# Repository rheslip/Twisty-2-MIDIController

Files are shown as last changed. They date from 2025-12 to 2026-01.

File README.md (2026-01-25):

# Twisty 2 MIDI Controller
2nd Generation of my Twisty MIDI controller using Raspberry Pi Pico or Pico 2.

The Twisty 2 MIDI controller has 16 parameter encoders with switches, 16 RGB LEDs, 2 menu encoders, 128x32 pixel OLED display, USB MIDI, TRS MIDI Out, and optional Bluetooth MIDI with Pico W or Pico 2W.
It provides four pages of MIDI controls and fully customizable MIDI messages, encoder ranges, switch functions and LED colors for each control. Text labels can be attached to each control as a visual aid to what the control does. You can save and recall up to 16 controller setups in the Pico's flash memory. STL files for a 3D printed case are provided as well.

Twisty 2 is a completely open source project - source code, KICad schematics and layout, gerber files and enclosure 3D files are in this archive.

Video Overview: https://youtu.be/-W1Gd_hKzS8

Jan 13/2026 - switched MIDI interfaces so they all use the Control Surface library and cleaned up the MIDI interface names - BLE MIDI note on/off works now. Fixed a bug in the init code. 

Jan 25/2026 - added code for a Moog SubHarmonicon like sequencer using the Twisty 2 hardware:

https://www.youtube.com/watch?v=RM_LAcxyHQQ

https://github.com/rheslip/Twisty-2-MIDIController/tree/main/source/Twisty2_Rhythmicon

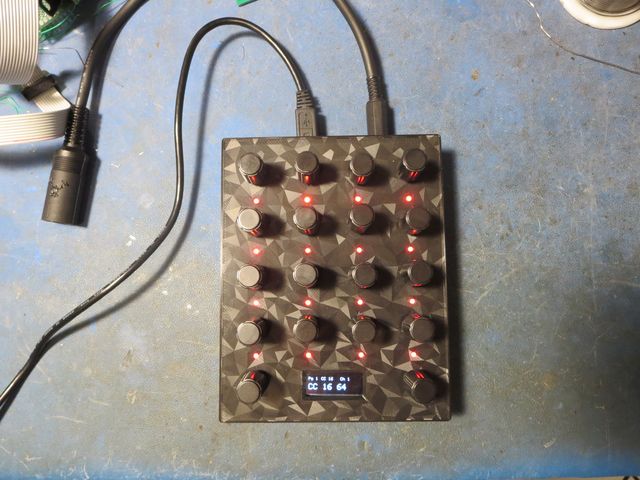
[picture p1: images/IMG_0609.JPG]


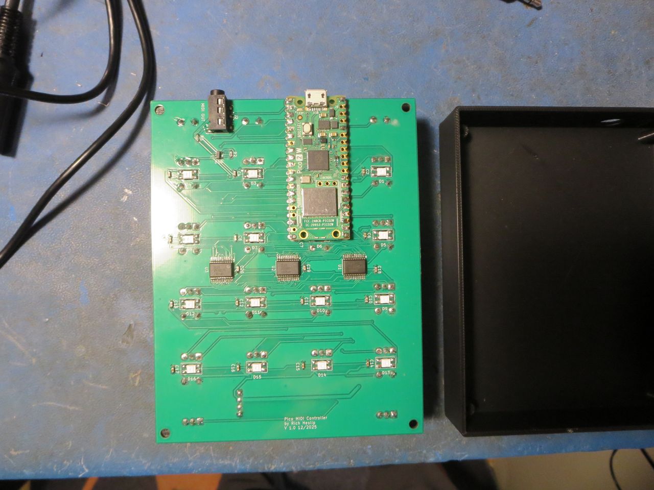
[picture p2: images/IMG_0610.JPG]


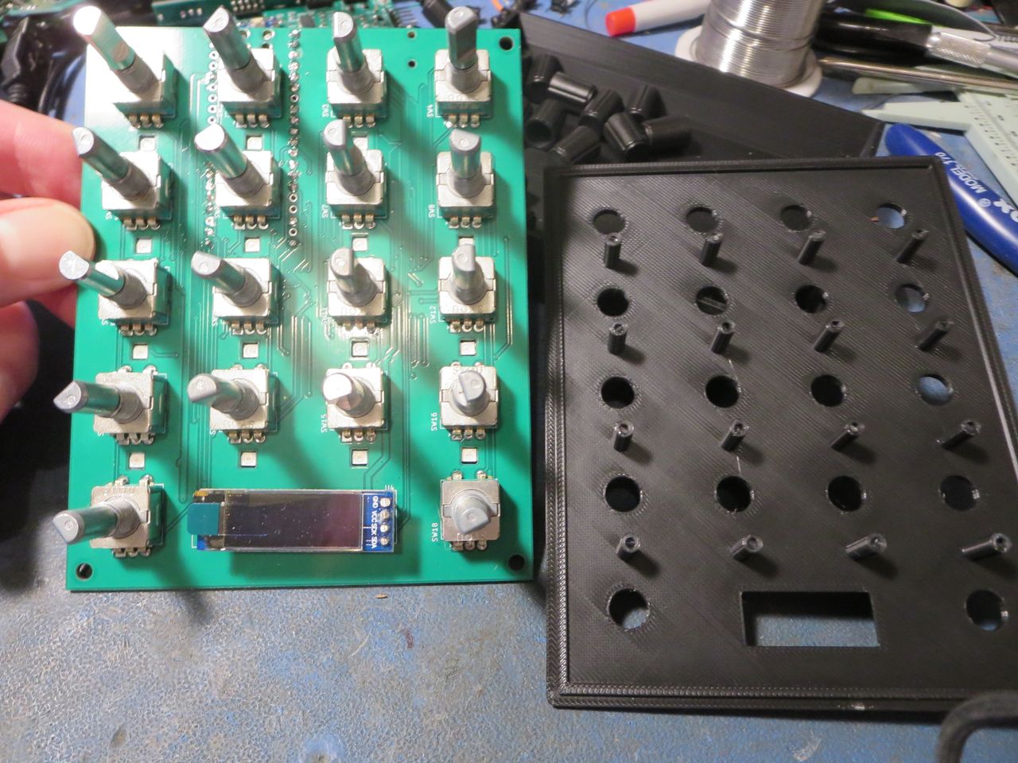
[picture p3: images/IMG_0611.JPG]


**Build Guide**

Solder the .1u caps, resistors and the diode. Solder the 16 SK6812 RGB leds making sure the orientation is correct and that the LEDs face the top side of the PCB. Solder the TRS MIDI out jack.

Solder the TSSOP 74HC4067s. I apply a very thin layer of flux to the pads and place the chip so its aligned on the pads. Using a fine tipped soldering iron tack one pin down with solder, adjust as needed and when the part is correctly aligned tack another pin down. Make sure the pins are sitting flat on the pads before you solder the rest. Solder each pin with very fine solder and don't worry about shorts between pins. Once all the pins are soldered examine your work with a magnifier and remove any shorts beween pins with fine solder wick.

Clip the support lugs off all the encoders - there was not enough room in the layout to accomodate them. The encoders have good mechanical support from the enclosure top anyway. The encoders mount from the TOP side of the board and are soldered on the bottom side. You **MUST** solder S2, S6, D2 and D6 **BEFORE** mounting the Pico board. Soldering S2, S6 and then the Pico makes soldering the Pico somewhat easier than soldering all the encoders first.

After all the encoders are soldered, mount the OLED display - temporarily mount the enclosure top as a guide to get the spacing from the display to the top correct.

Hardest part of the build is soldering the three TSSOP 74HC4067 analog MUXes. If encoders aren't working, recheck the soldering on these chips - most faults will be here! Rest of the build is straightforward.

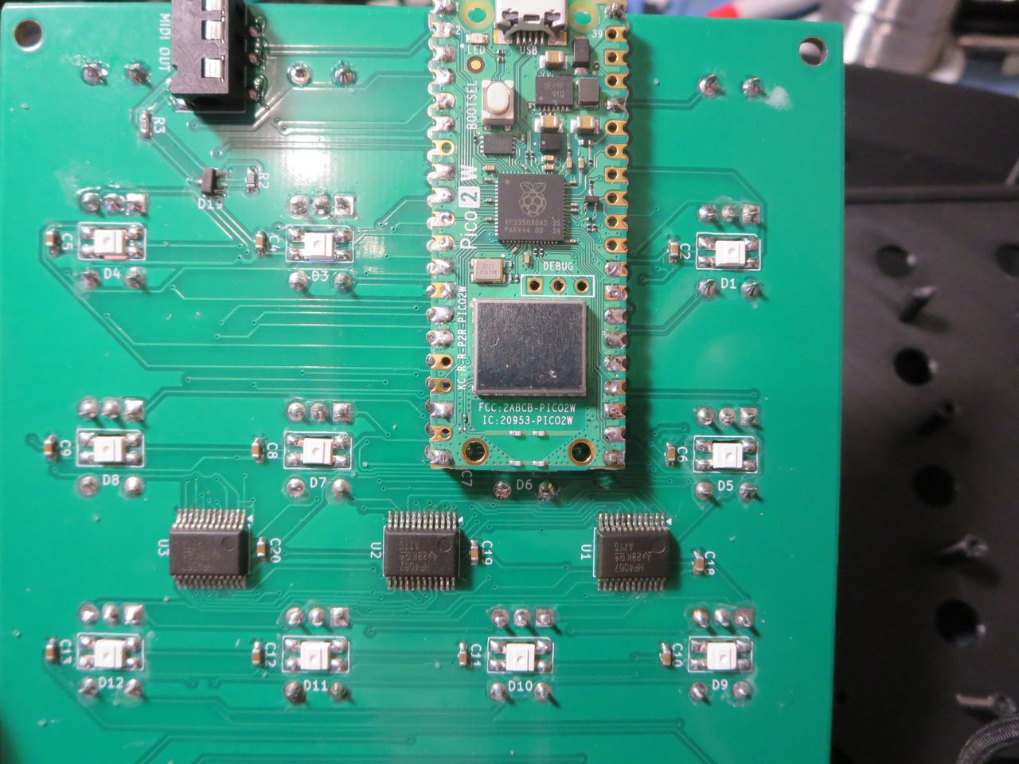
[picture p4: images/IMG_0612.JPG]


Pico can be mounted with header strips. I used header pins in the corners and short wires to connect the Pico to the PCB which makes the Pico board a lot easier to remove if needed.

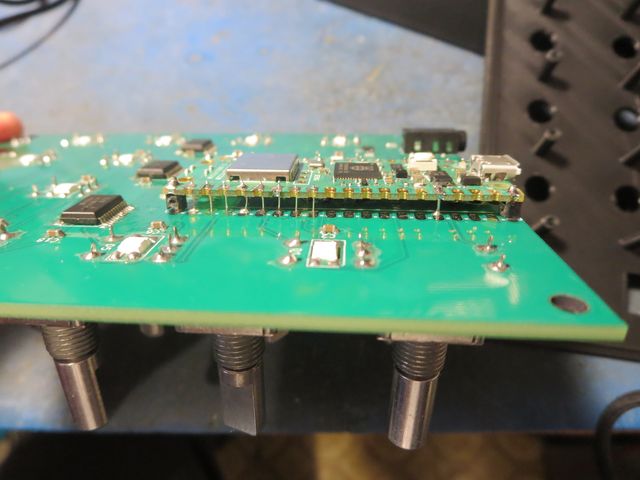
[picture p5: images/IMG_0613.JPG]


Side view of OLED mounting

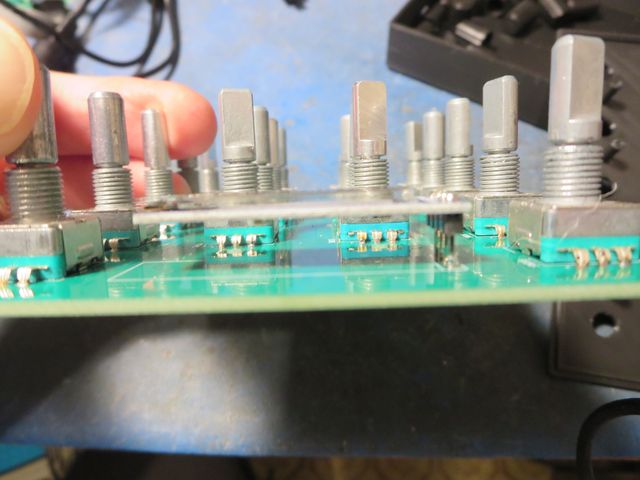
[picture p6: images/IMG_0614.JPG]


**Enclosure**

The prototype enclosure was printed on a Bambu P1S with black PLA+ filament. For the most part the stock filament settings were used. Slowing down the first layer speeds by 50% helps with adhesion and finish if you are using a textured build plate. The light pipe holes in the top had to be drilled a bit to fit 1.75mm transparent PETG which was lightly glued to hold it in place. Use small screws to attach the PCB to the standoffs in the enclosure bottom. Slide the enclosure top over the encoder shafts and hold it in place with encoder nuts.

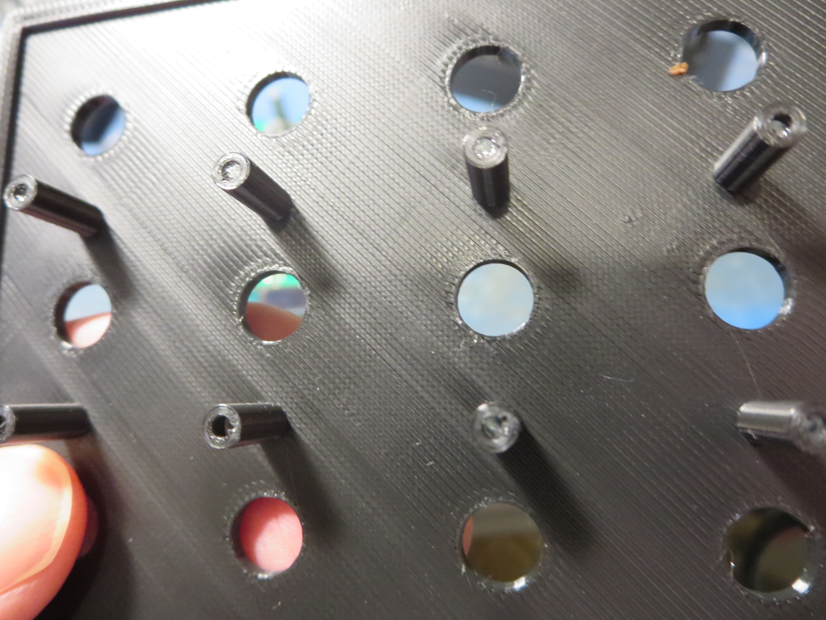
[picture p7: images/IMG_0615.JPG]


**User Guide**

The top 16 controls (control=encoder+switch) are used to send MIDI CC messages, program change messages or or note on/off messages depending on how the controls are configured. The two extra controls at the bottom are used in conjunction with the OLED display to configure controls, save configurations and recall configurations.

The RGB LEDs associated with each control normally show the state of whatever was last used - encoder as a color and switch states as off or bright white. Encoder LED brightness changes as the control is moved to give a relative idea of the encoder setting. Double click the bottom left control to toggle between showing encoder states and switch states.

Rotate bottom left encoder to move between the 4 pages of controls. Default colors for each page are Red (page 1), Orange (page 2), Green (page ) and Aqua (page 4).

The top line of the OLED display shows the current page, the last used control, its message type and MIDI channel. The larger text below that shows a label if one has been configured and the last value that was sent for that control.

**The Configuration Menu**

Clicking the bottom left control will bring up a configuration menu to edit the last control that was used. The LED for that control will flash to indicate it is selected for editing. To select a different control when in edit mode either press a control switch to choose it or use bottom left encoder to scroll to a different control on the current page.

When in edit mode use the bottom right encoder the scroll through the edit menu items. Click the bottom right control switch to select an item - a "*" character will appear beside the item to indicate it is being edited. Use the bottom right encoder to change the value for the item and click the bottom right encoder switch to select a value.

Click the bottom left encoder again to exit the configuration edit menu.

**Configuration Menu Items:**

**Enc MIDI Ch.** - selects the MIDI channel that the selected encoder will send CC messages on

**Enc CC No.**  - selects the CC number for this encoder. The default CC assignments are 16-31 for page 1, 32-47 for page 2, 48-63 for page 3 and 64-79 for page 4

**Enc Label** - default is "CC". There are approximately 100 common audio terms (e.g. "Level", "Filter", "Track"...) that can be selected as an aid for remembering the function of the control. The label will be displayed instead of the CC number whenever this encoder is used.

**Enc Color** - selects the LED color for this encoder - Red, Orange, Green, Aqua, Blue or Violet. This is useful for grouping control functions by color.

**Enc Min** - minimum CC value that will be sent when the encoder is rotated - defaults to 0

**Enc Max** - maximum CC value that will be sent when the encoder is rotated - defaults to 127. 
**Note** If the minimum setting is higher than the maximum the encoder will reverse ie rotating clockwise sends a lower CC value.

**Switch MIDI Ch.** - selects the MIDI channel that the selected switch will send CC messages on

**Switch Mode** - selects either momentary mode (press for max value, release for min value) or toggle mode (select min or max value on alternate presses)

**Switch Type** - selects switch function:

     **CC** = send CC messages 
 
     **PC** = send program change messages
 
     **Note** = send Note on/off messages
 
     **SetEnc** = when the switch is activated, set the associated encoder on this control to Maxvalue. This provides a quick way to set an encoder to a specific value e.g. set a filter to flat response.
 
**Switch CC No.** - selects the CC number for this switch. This selection only applies when the switch type is send CC messages. The default switch CC assignments are the same as the associated encoder but on MIDI channel 2. 

**Switch Label** - same as encoder label - a memory aid for what the switch does

**Switch Min** - CC, PC or note value sent when the switch changes to its inactive state. defaults to 0

**Switch Max** - CC, PC or note value sent when the switch changes to its active state. defaults to 127. When switch type is SetEnc, sets associated encoder to this value.

**The Save/Load Menu**

Clicking the bottom right encoder enters the save/load menu. Twisty 2 supports saving and loading up to 16 different configurations in the Pico's flash memory.

**Note** You must select an FS size in the Arduino Pico Tools menu - 128K or larger is suggested. The application will automatically format a new FS if it has not been used before. Internally the application uses the LittleFS filesystem and stores configurations as JSON files.

**Save/Load Menu Items:**

**Slot** - selects the slot number 1-16 to save the current configuration to.

**Action** - select Load to load an already saved configuration from the selected slot. Save will save the current configuration to the selected slot. Format will reformat the LittleFS partition - this will ERASE ALL previously saved configurations.

**Confirm** - select Yes to confirm the selected action. The app will **NOT** warn you if you are about to overwrite an existing configuration. If Yes is selected the requested action will be performed, a success/fail message will appear and the Save/load Menu will exit.

**Note** You will get an error message if you attempt to load a configuration slot that hasn't previously been saved to.

To exit the Save/Load menu without changing anything click the bottom left control switch.

**Building the Firmware**

The app was written in Arduino 2.3.7 with the Pico Arduino board support package installed. Select the board type as Pico, Pico 2, Pico 2 or Pico 2W depending on the board you used. The prototype was tested with both a Pico W and a Pico 2 W. In the tools menu select the FS size you want (128k or more is recommended), IP/Bluetooth stack as IPV4 + Bluetooth if you want BLE MIDI, and select the USB stack as Adafruit TinyUSB. This app should not need overclocking since the CPU demands are light.

If you want BLE MIDI, use a Pico W or Pico 2W and uncomment the #define BLUETOOTH directive near the top of the main source file.

Note: I used the Control Surface library because it was the only one I could find that supports BLE MIDI for Arduino Pico. It will give you a warning about supported platforms when you compile but the library does work on the RP2040 and RP2350.

**Library Dependencies**

Adafruit Graphics

Adafruit SSD1306 driver

Adafruit TinyUSB

Adafruit NeoPixel

Arduino MIDI

Arduino JSON  https://arduinojson.org/

Control Surface  https://github.com/tttapa/Control-Surface

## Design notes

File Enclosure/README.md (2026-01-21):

Enclosure files for the Twisty 2 MIDI Controller

There are two versions of the base - one has cutouts for the Pico USB connector and the TRS MIDI jack, and another which adds cutouts for a slide switch and USB-C for a battery charger module.

I used a 1S TP4056 5V 28x17mm module from Aliexpress. The case has a little box to hold the module - put some 2mm thick double sided tape in the bottom of the box and press the module into place. Its tight so the module may need a little sanding to fit.
Make sure you change the charging rate to a safe level for your battery! On the modules I bought R3 adjusts the charge rate - see the TP4056 datasheet.

https://www.aliexpress.com/item/1005007730039023.html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

The stepup regulator is a 0.9v to 5V input, 5V output module. Solder the GND pin to Pico pin 38 GND and the 5V output pin to Pico pin 39 VSys. I added a 10k:10k divider from battery input Vin to GND with the center to pin 34 ADC3 which allows the battery voltage to be monitored.

https://www.aliexpress.com/item/1005003375824265.html?spm=a2g0o.order_list.order_list_main.369.4d9a1802hPwpIL

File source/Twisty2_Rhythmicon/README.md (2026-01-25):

# PicoRhythmicon - a Subharmonicon-like sequencer using the Twisty 2 MIDI Controller hardware

The Twisty 2 was designed to be a MIDI controller but also as a platform for creating other MIDI devices. This one is a sequencer similar to the Moog Subharmonicon. The Subharmonicon sequencer is based on a very old polyrhythmic instrument called the Rhythmicon.

Demo and tutorial video: 

I suggest you also watch a tutorial video on the Moog Subharmonicon to get a better understanding of how this sequencer works.

**User Guide**

The top 16 encoders are set up as three rows of (four step) sequencers and a bottom row of clock dividers. Notes are set by rotating the encoders. The top three rows of the display show the MIDI notes that will be sent for each step of the three sequencers. The display shows the clock divider values on the botton row.

The 4 clock divider LED colors are (L-R) Red, Green, Blue and Purple. Rotate the encoders counterclockwise to increase the divider i.e. slow down the clock. To connect a clock divider to a sequencer, press the encoder button on the sequencer's row that corresponds to the clock divider's column. The step encoder's LED will change to the same color as the clock divider to indicate that sequencer is connected to that divider.

The internal master clock is 24 pulses per quarter note/6 = sixteenth notes when the clock divider is set to 1. Changing the clock divider to 2 results in eighth notes, 3 is dotted eighths, 4 is quarter note etc. The maximum clock divider is 128 which is 8 bars. If a 24 PPQN MIDI clock is sent to the PicoRhythmicon via it's USB or BLE MIDI interface it will automatically sync to it. It also responds to MIDI transport messages.

**The Setup Menu**

Clicking the bottom right encoder will bring up a setup menu. When in edit mode use the bottom right encoder the scroll through the edit menu items. Click the bottom right control switch to select an item - a "*" character will appear beside the item to indicate it is being edited. Use the bottom right encoder to change the value for the item and click the bottom right encoder switch to select a value. Click the bottom left encoder or double click the bottom right encoder to exit the setup menu.

**Setup Menu Items:**

Each of the three sequencers has these setup options:

**Root** - root note for the scale quantizer (default C3 MIDI note 60). The note for any given step is the root note plus an offset adjusted by the step's encoder.

**Scale**  - selects the scale for the sequencer from CHROMATIC, MAJOR, MINOR, HARMONIC_MINOR, MAJOR_PENTATONIC, MINOR_PENTATONIC, DORIAN, PHRYGIAN, LYDIAN, or MIXOLYDIAN. The note shown on the display is the quantized value. Because of this you may have to rotate the encoder a few steps to get to the next note in the scale.

**Step mode** - changes the way the sequencer steps from one note to the next: 

Fwd - steps from left to right

Rev - steps from right to left

Pong - reverses direction on the first and last steps

Walk - random walk - the sequencer randomly steps to the right or the left 

Rand - a random step is chosen

**MIDI Out** - MIDI channel that this sequencer will send notes on

**MIDI In** - MIDI channel that this sequencer will respond to incoming transpose notes. Transpose is calculated as an offset from MIDI note 60, which is added to the root note plus an offset adjusted by the step's encoder. i.e. the note sent on any given step is calculated as root + step offset + (transpose note - 60)

**BPM** - sets the internal clock BPM. As noted above, the unit will sync to an external MIDI clock sent via the BLE or USB interfaces.

**Bat Voltage** - shows the battery voltage if the hardware supports it. See the enclosure README file for the hardware mods needed for battery operation.

**Building the Firmware**

The app was written in Arduino 2.3.7 with the Pico Arduino board support package installed. Select the board type as Pico, Pico 2, Pico 2 or Pico 2W depending on the board you used. The prototype was tested with both a Pico W and a Pico 2 W. In the tools menu select IP/Bluetooth stack as IPV4 + Bluetooth if you want BLE MIDI, and select the USB stack as Adafruit TinyUSB. This app should not need overclocking since the CPU demands are light.

If you want BLE MIDI, use a Pico W or Pico 2W and uncomment the #define BLUETOOTH directive near the top of the main source file.

Note: I used the Control Surface library because it was the only one I could find that supports BLE MIDI for Arduino Pico. It will give you a warning about supported platforms when you compile but the library does work on the RP2040. It will also work on the RP2350 but requires some modifications to the conditionals to compile correctly.

**Library Dependencies**

Adafruit Graphics

Adafruit SSD1306 driver

Adafruit TinyUSB

Adafruit NeoPixel

Control Surface  https://github.com/tttapa/Control-Surface

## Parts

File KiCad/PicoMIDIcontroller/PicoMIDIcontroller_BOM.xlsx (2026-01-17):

Reference | Qty | Value | Footprint | Link | Comments | Datasheet
A1 | 1 | RaspberryPi_Pico |  |  | Pico,Pico W, Pico2, Pico 2W | https://datasheets.raspberrypi.com/pico/pico-datasheet.pdf
C2,C3,C4,C5,C6,C7,C8,C9,C10,C11,C12,C13,C14,C15,C16,C17,C18,C19,C20 | 19 | .1u | 0603 |  |  | ~
D1,D2,D3,D4,D5,D6,D7,D8,D9,D10,D11,D12,D13,D14,D15,D16 | 16 | SK6812E-MINI | SK6812_MINI-E_rearmount | https://www.aliexpress.com/item/1005005193716172.html | best price is on Aliexpress | https://cdn-shop.adafruit.com/product-files/2686/SK6812MINI_REV.01-1-2.pdf
D19 | 1 | BAT54S | SOT-23 |  | make sure you use the "S" pinout | https://www.diodes.com/assets/Datasheets/ds11005.pdf
H1,H2,H3,H4 | 4 | MountingHole | 3.2mm_M3 |  |  | ~
J2 | 1 | AudioJack4 | PJ-320D-4A_Horizontal | https://www.aliexpress.com/item/1005010770707376.html?curPageLogUid=zL5tGp3dUZi3 | SMT, 3 leads on one side, one on the other | ~
R2 | 1 | 33 | 0603 |  |  | ~
R3 | 1 | 10 | 0603 |  |  | ~
SW1,SW2,SW3,SW4,SW5,SW6,SW7,SW8,SW9,SW10,SW11,SW12,SW13,SW14,SW15,SW16,SW17,SW18 | 18 | RotaryEncoder_Switch | EC11E-Switch_Vertical | https://www.digikey.ca/en/products/detail/bourns-inc/PEC11R-4220F-S0024/4499660 | PEC11R-4020F-S0024 - no detents, PEC11R-4220F-S0024 24 detents. Very cheap on Aliexpress | https://www.bourns.com/docs/Product-Datasheets/PEC11R.pdf
U1,U2,U3 | 3 | CD74HC4067PWR | 24-TSSOP 7.8mm × 6.4mm | https://www.digikey.ca/en/products/detail/texas-instruments/CD74HC4067PWR/26639687 |  | http://www.ti.com/lit/ds/symlink/cd74hc4067.pdf
U4 | 1 | SSD1603_OLED | 1x04_P2.54mm_Vertical | https://www.aliexpress.com/item/32672229793.html | available on Amazon as well

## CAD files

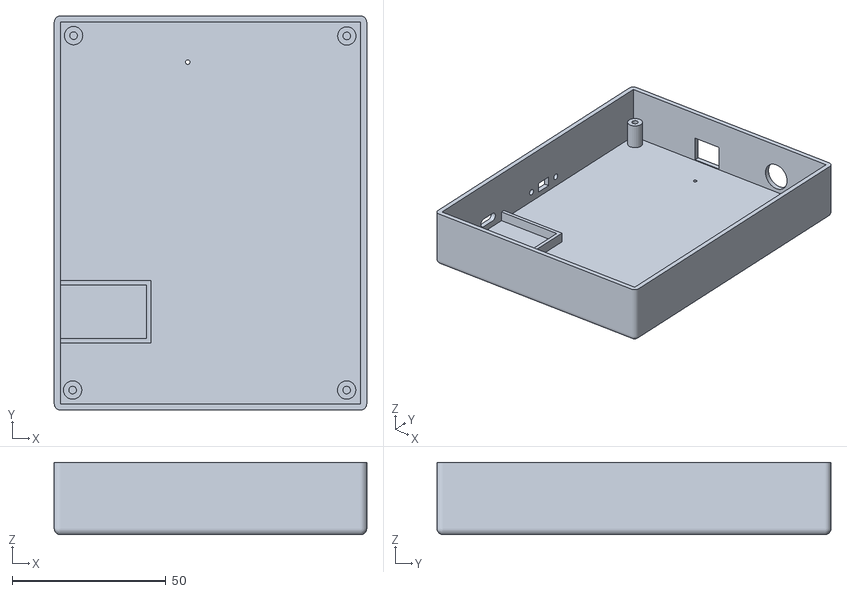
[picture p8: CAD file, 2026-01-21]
Enclosure/Pico Midicontroller Base Battery Powered.stl
101.8 x 128.3 x 23.6

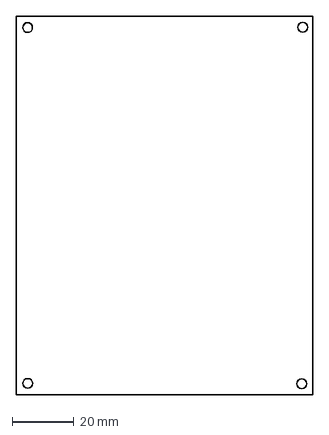
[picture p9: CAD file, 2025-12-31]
KiCad/PicoMIDIcontroller/PCB Outline.dxf
95.8 x 122.3 mm

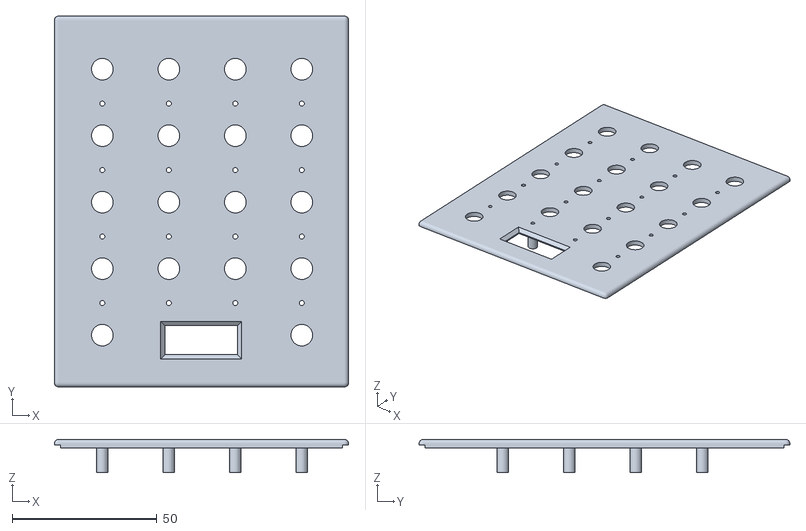
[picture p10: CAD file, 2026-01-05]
Enclosure/Pico MIDIcontroller Top.stl
101.8 x 128.3 x 11.5

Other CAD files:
Enclosure/Pico MIDIController Base.stl

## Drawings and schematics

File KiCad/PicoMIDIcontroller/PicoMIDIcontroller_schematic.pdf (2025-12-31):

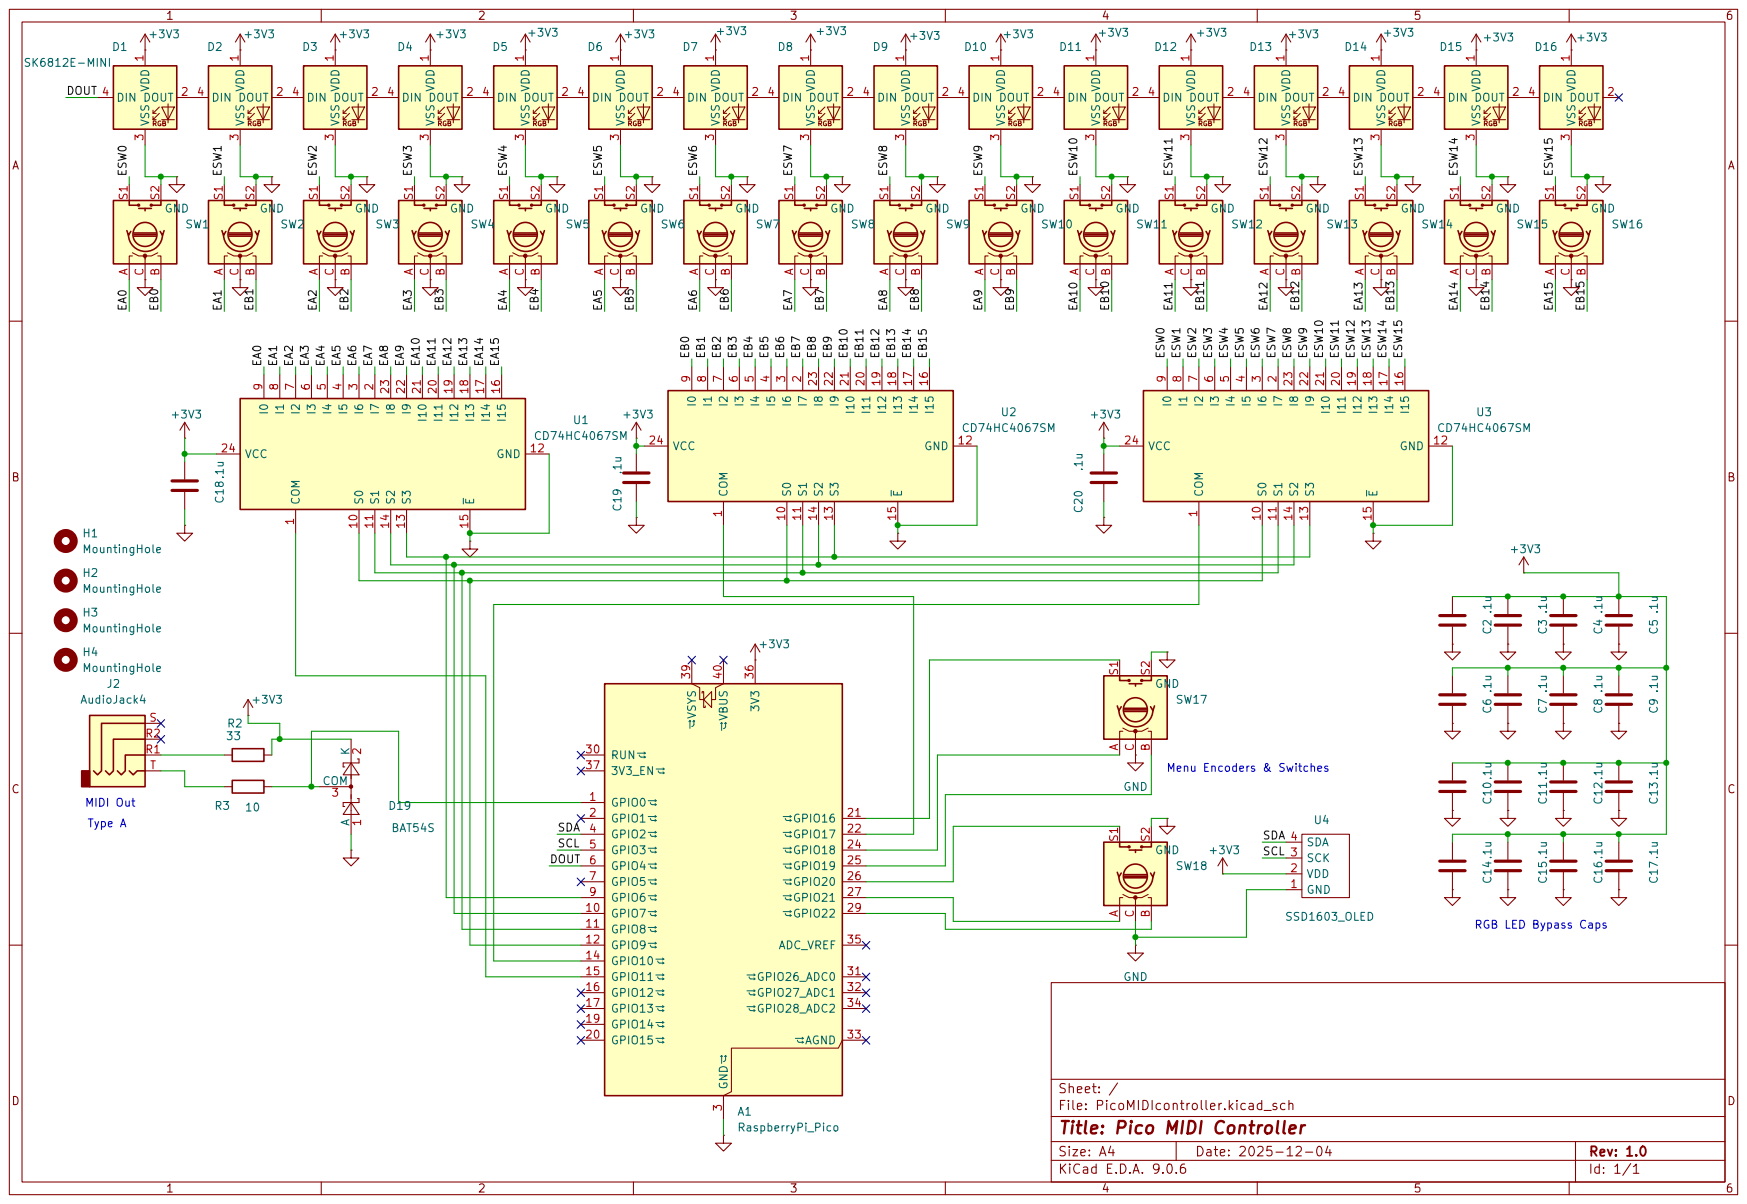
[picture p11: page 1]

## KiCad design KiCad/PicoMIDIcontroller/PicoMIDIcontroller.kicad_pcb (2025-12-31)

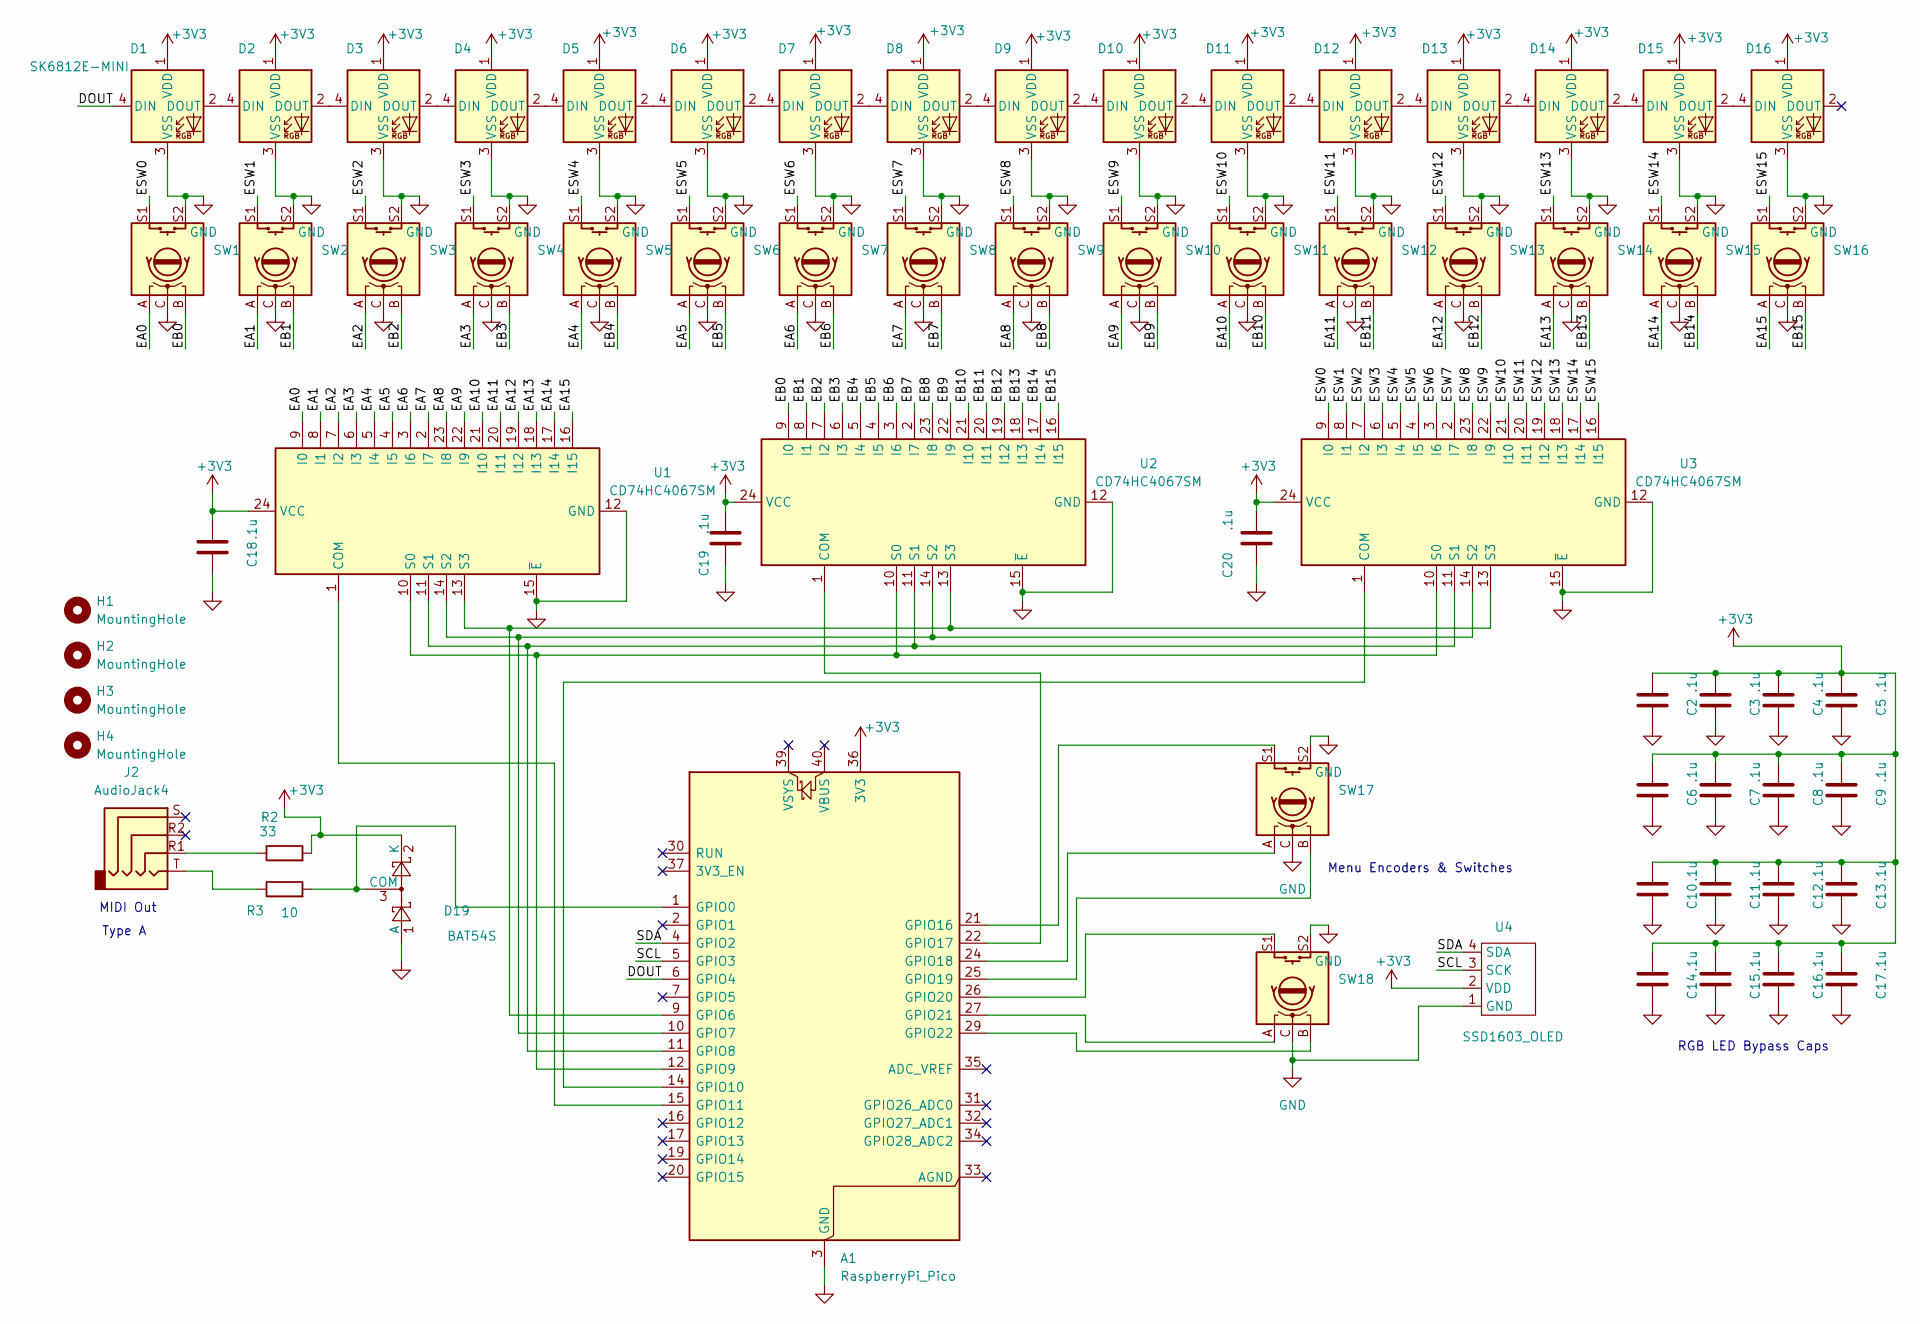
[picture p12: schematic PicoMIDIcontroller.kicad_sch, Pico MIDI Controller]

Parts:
A1: RaspberryPi_Pico; RaspberryPi_Pico_Common_nokeepout
C2, C3, C4, C5, C6, C7, C8, C9, C10, C11, C12, C13, C14, C15, C16, C17, C18, C19, C20: .1u; C_0603_1608Metric_Pad1.08x0.95mm_HandSolder
D1, D2, D3, D4, D5, D6, D7, D8, D9, D10, D11, D12, D13, D14, D15, D16: SK6812E-MINI; LED_OPSCO_SK6812_MINI-E_5.0x5.0mm_P3.1mm_rearmount
D19: BAT54S; SOT-23
H1, H2, H3, H4: MountingHole; MountingHole_3.2mm_M3
J2: AudioJack4; Jack_3.5mm_KoreanHropartsElec_PJ-320D-4A_Horizontal
R2: 33; R_0603_1608Metric_Pad0.98x0.95mm_HandSolder
R3: 10; R_0603_1608Metric_Pad0.98x0.95mm_HandSolder
SW1, SW2, SW3, SW4, SW5, SW6, SW7, SW8, SW9, SW10, SW11, SW12, SW13, SW14, SW15, SW16, SW17, SW18: RotaryEncoder_Switch; RotaryEncoder_Alps_EC11E-Switch_Vertical_H20mm_topsolder
U1, U2, U3: CD74HC4067SM; SSOP-24_5.3x8.2mm_P0.65mm
U4: SSD1603_OLED; PinHeader_1x04_P2.54mm_Vertical

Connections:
+3V3: A1.36 (3V3), C2.2, C3.2, C4.2, C5.2, C6.2, C7.2, C8.2, C9.2, C10.2, C11.2, C12.2, C13.2, C14.2, C15.2, C16.2, C17.2, C18.2, C19.2, C20.2, D1.1 (VDD), D2.1 (VDD), D3.1 (VDD), D4.1 (VDD), D5.1 (VDD), D6.1 (VDD), D7.1 (VDD), D8.1 (VDD), D9.1 (VDD), D10.1 (VDD), D11.1 (VDD), D12.1 (VDD), D13.1 (VDD), D14.1 (VDD), D15.1 (VDD), D16.1 (VDD), D19.2 (K), R2.2, U1.24 (VCC), U2.24 (VCC), U3.24 (VCC), U4.2 (VDD); also elsewhere on the board
/DOUT: A1.6 (GPIO4), D1.4 (DIN); also elsewhere on the board
/EA0: SW1.A, U1.9 (I0)
/EA1: SW2.A, U1.8 (I1)
/EA2: SW3.A, U1.7 (I2)
/EA3: SW4.A, U1.6 (I3)
/EA4: SW5.A, U1.5 (I4)
/EA5: SW6.A, U1.4 (I5)
/EA6: SW7.A, U1.3 (I6)
/EA7: SW8.A, U1.2 (I7)
/EA8: SW9.A, U1.23 (I8)
/EA9: SW10.A, U1.22 (I9)
/EA10: SW11.A, U1.21 (I10)
/EA11: SW12.A, U1.20 (I11)
/EA12: SW13.A, U1.19 (I12)
/EA13: SW14.A, U1.18 (I13)
/EA14: SW15.A, U1.17 (I14)
/EA15: SW16.A, U1.16 (I15)
/EB0: SW1.B, U2.9 (I0)
/EB1: SW2.B, U2.8 (I1)
/EB2: SW3.B, U2.7 (I2)
/EB3: SW4.B, U2.6 (I3)
/EB4: SW5.B, U2.5 (I4)
/EB5: SW6.B, U2.4 (I5)
/EB6: SW7.B, U2.3 (I6)
/EB7: SW8.B, U2.2 (I7)
/EB8: SW9.B, U2.23 (I8)
/EB9: SW10.B, U2.22 (I9)
/EB10: SW11.B, U2.21 (I10)
/EB11: SW12.B, U2.20 (I11)
/EB12: SW13.B, U2.19 (I12)
/EB13: SW14.B, U2.18 (I13)
/EB14: SW15.B, U2.17 (I14)
/EB15: SW16.B, U2.16 (I15)
/ESW0: SW1.S1, U3.9 (I0)
/ESW1: SW2.S1, U3.8 (I1)
/ESW2: SW3.S1, U3.7 (I2)
/ESW3: SW4.S1, U3.6 (I3)
/ESW4: SW5.S1, U3.5 (I4)
/ESW5: SW6.S1, U3.4 (I5)
/ESW6: SW7.S1, U3.3 (I6)
/ESW7: SW8.S1, U3.2 (I7)
/ESW8: SW9.S1, U3.23 (I8)
/ESW9: SW10.S1, U3.22 (I9)
/ESW10: SW11.S1, U3.21 (I10)
/ESW11: SW12.S1, U3.20 (I11)
/ESW12: SW13.S1, U3.19 (I12)
/ESW13: SW14.S1, U3.18 (I13)
/ESW14: SW15.S1, U3.17 (I14)
/ESW15: SW16.S1, U3.16 (I15)
/SCL: A1.5 (GPIO3), U4.3 (SCK); also elsewhere on the board
/SDA: A1.4 (GPIO2), U4.4 (SDA); also elsewhere on the board
GND: A1.3 (GND), A1.8 (GND), A1.13 (GND), A1.18 (GND), A1.23 (GND), A1.28 (GND), A1.38 (GND), C2.1, C3.1, C4.1, C5.1, C6.1, C7.1, C8.1, C9.1, C10.1, C11.1, C12.1, C13.1, C14.1, C15.1, C16.1, C17.1, C18.1, C19.1, C20.1, D1.3 (VSS), D2.3 (VSS), D3.3 (VSS), D4.3 (VSS), D5.3 (VSS), D6.3 (VSS), D7.3 (VSS), D8.3 (VSS), D9.3 (VSS), D10.3 (VSS), D11.3 (VSS), D12.3 (VSS), D13.3 (VSS), D14.3 (VSS), D15.3 (VSS), D16.3 (VSS), D19.1 (A), SW1.C, SW1.S2, SW2.C, SW2.S2, SW3.C, SW3.S2, SW4.C, SW4.S2, SW5.C, SW5.S2, SW6.C, SW6.S2, SW7.C, SW7.S2, SW8.C, SW8.S2, SW9.C, SW9.S2, SW10.C, SW10.S2, SW11.C, SW11.S2, SW12.C, SW12.S2, SW13.C, SW13.S2, SW14.C, SW14.S2, SW15.C, SW15.S2, SW16.C, SW16.S2, SW17.C, SW17.S2, SW18.C, SW18.S2, U1.12 (GND), U1.15 (~E), U2.12 (GND), U2.15 (~E), U3.12 (GND), U3.15 (~E), U4.1 (GND); also elsewhere on the board
unnamed 53: A1.1 (GPIO0), D19.3 (COM), R3.2; also elsewhere on the board
unnamed 54: A1.9 (GPIO6), U1.13 (S3), U2.13 (S3), U3.13 (S3); also elsewhere on the board
unnamed 55: A1.10 (GPIO7), U1.14 (S2), U2.14 (S2), U3.14 (S2); also elsewhere on the board
unnamed 56: A1.11 (GPIO8), U1.11 (S1), U2.11 (S1), U3.11 (S1); also elsewhere on the board
unnamed 57: A1.12 (GPIO9), U1.10 (S0), U2.10 (S0), U3.10 (S0); also elsewhere on the board
unnamed 58: A1.14 (GPIO10), U3.1 (COM); also elsewhere on the board
unnamed 59: A1.15 (GPIO11), U1.1 (COM); also elsewhere on the board
unnamed 60: A1.21 (GPIO16), SW17.S1; also elsewhere on the board
unnamed 61: A1.22 (GPIO17), U2.1 (COM); also elsewhere on the board
unnamed 62: A1.24 (GPIO18), SW17.A; also elsewhere on the board
unnamed 63: A1.25 (GPIO19), SW17.B; also elsewhere on the board
unnamed 64: A1.26 (GPIO20), SW18.S1; also elsewhere on the board
unnamed 65: A1.27 (GPIO21), SW18.A; also elsewhere on the board
unnamed 66: A1.29 (GPIO22), SW18.B; also elsewhere on the board
unnamed: D1.2 (DOUT), D2.4 (DIN)
unnamed: D2.2 (DOUT), D3.4 (DIN)
unnamed: D3.2 (DOUT), D4.4 (DIN)
unnamed: D4.2 (DOUT), D5.4 (DIN)
unnamed: D5.2 (DOUT), D6.4 (DIN)
unnamed: D6.2 (DOUT), D7.4 (DIN)
unnamed: D7.2 (DOUT), D8.4 (DIN)
unnamed: D8.2 (DOUT), D9.4 (DIN)
unnamed: D9.2 (DOUT), D10.4 (DIN)
unnamed: D10.2 (DOUT), D11.4 (DIN)
unnamed: D11.2 (DOUT), D12.4 (DIN)
unnamed: D12.2 (DOUT), D13.4 (DIN)
unnamed: D13.2 (DOUT), D14.4 (DIN)
unnamed: D14.2 (DOUT), D15.4 (DIN)
unnamed: D15.2 (DOUT), D16.4 (DIN)
unnamed: J2.R1, R2.1
unnamed: J2.T, R3.1

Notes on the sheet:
MIDI Out
RGB LED Bypass Caps
Menu Encoders & Switches
Type A

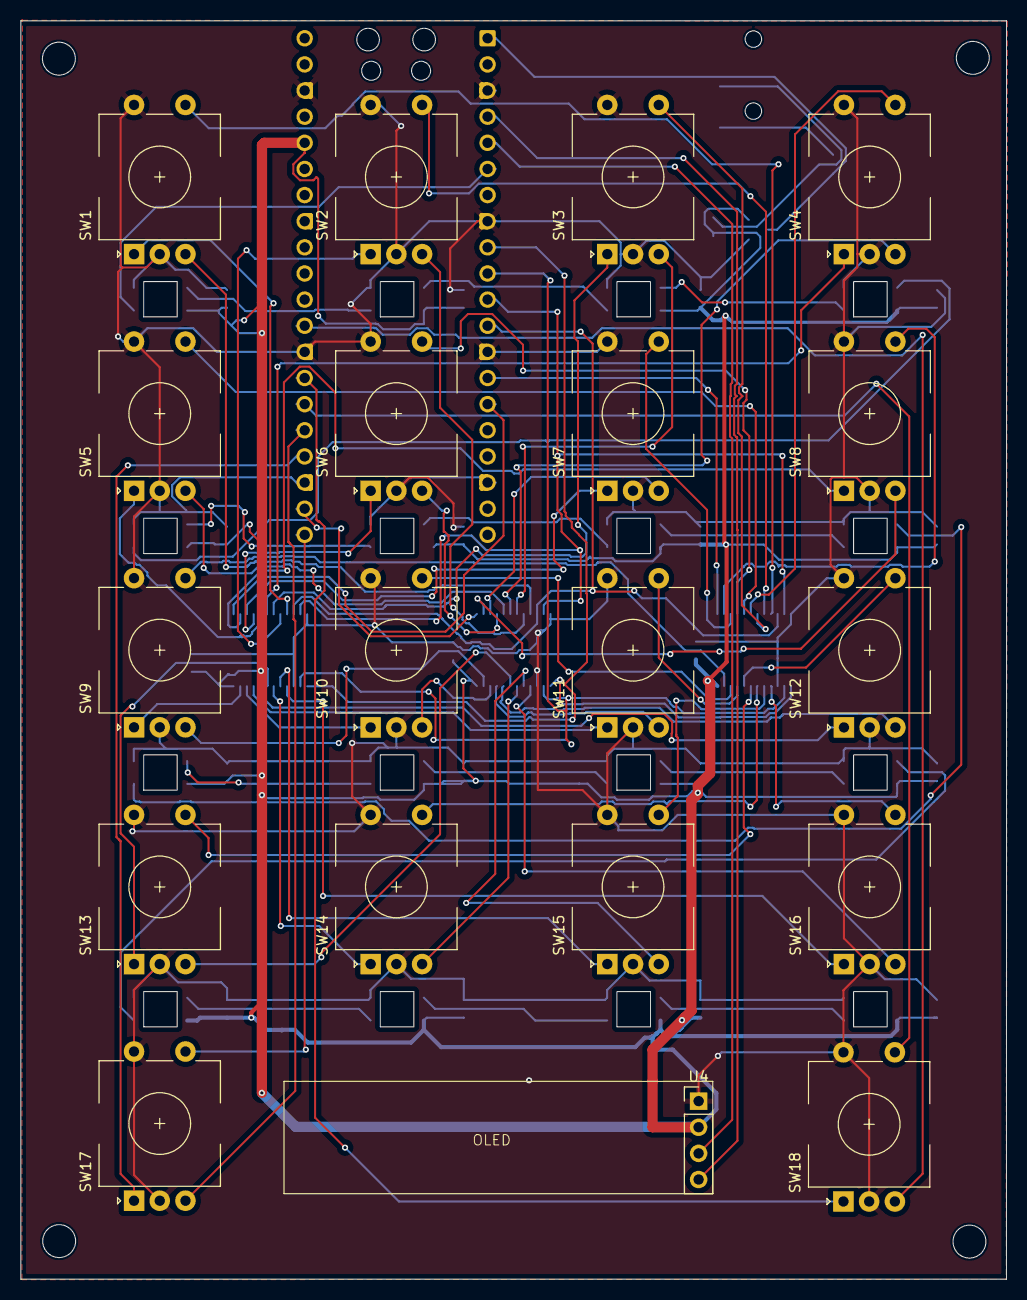
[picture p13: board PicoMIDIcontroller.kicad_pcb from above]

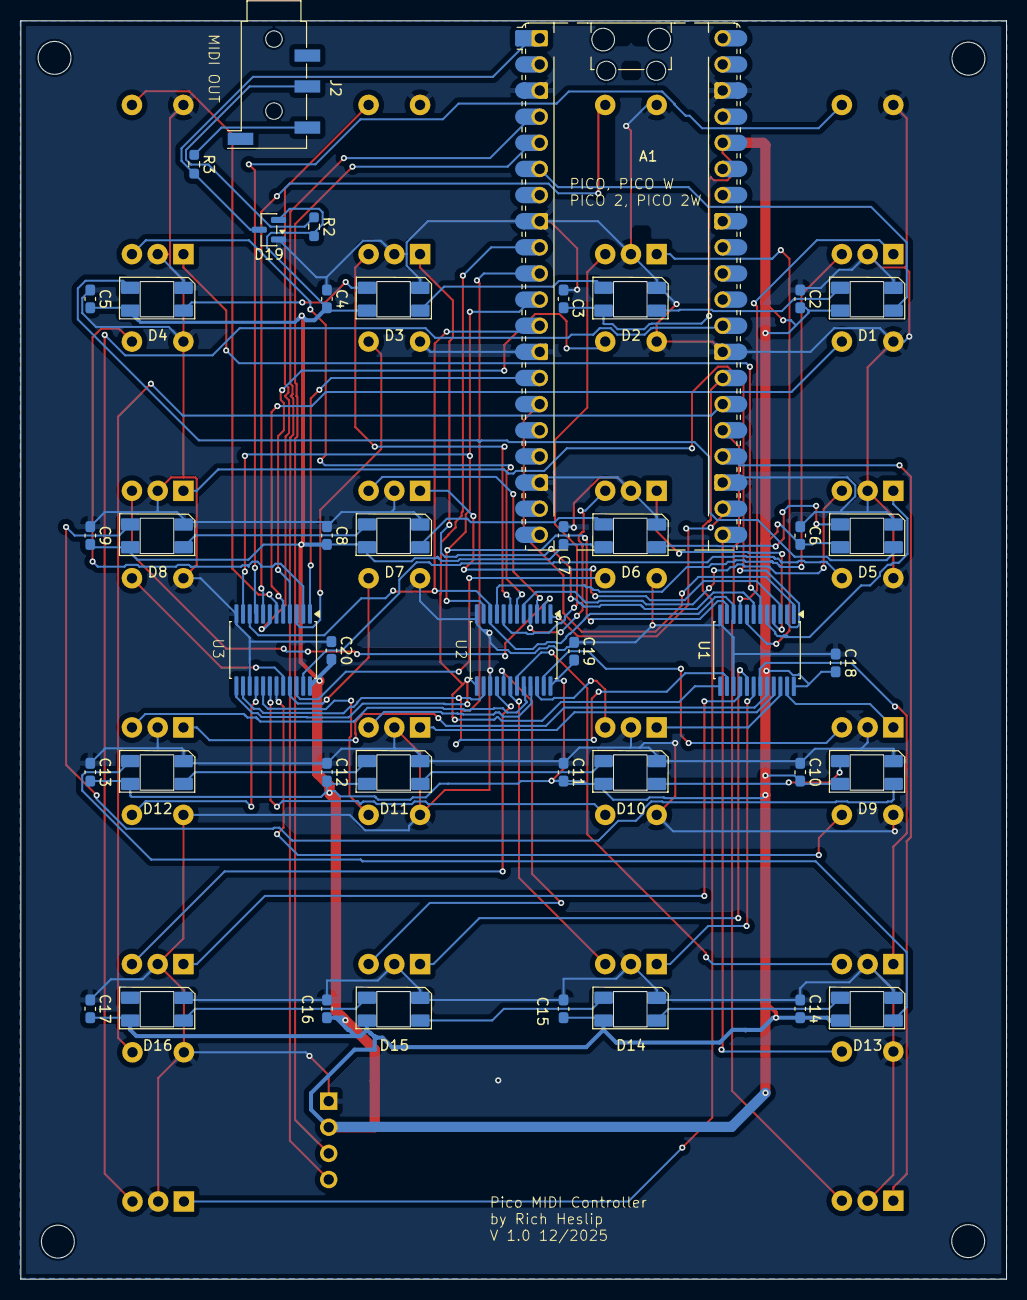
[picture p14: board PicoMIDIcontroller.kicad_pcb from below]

Board: 2 copper layers, 95.8 x 122.3 mm, 66 parts (43 on the bottom side), 84 nets.

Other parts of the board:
A1 : RaspberryPi_Pico; RaspberryPi_Pico_Common_nokeepout

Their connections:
+3V3: A1.36 (3V3); also elsewhere on the board
/DOUT: A1.6 (GPIO4); also elsewhere on the board
/SCL: A1.5 (GPIO3); also elsewhere on the board
/SDA: A1.4 (GPIO2); also elsewhere on the board
GND: A1.3 (GND), A1.8 (GND), A1.13 (GND), A1.18 (GND), A1.23 (GND), A1.28 (GND), A1.38 (GND); also elsewhere on the board
unnamed 53: A1.1 (GPIO0); also elsewhere on the board
unnamed 54: A1.9 (GPIO6); also elsewhere on the board
unnamed 55: A1.10 (GPIO7); also elsewhere on the board
unnamed 56: A1.11 (GPIO8); also elsewhere on the board
unnamed 57: A1.12 (GPIO9); also elsewhere on the board
unnamed 58: A1.14 (GPIO10); also elsewhere on the board
unnamed 59: A1.15 (GPIO11); also elsewhere on the board
unnamed 60: A1.21 (GPIO16); also elsewhere on the board
unnamed 61: A1.22 (GPIO17); also elsewhere on the board
unnamed 62: A1.24 (GPIO18); also elsewhere on the board
unnamed 63: A1.25 (GPIO19); also elsewhere on the board
unnamed 64: A1.26 (GPIO20); also elsewhere on the board
unnamed 65: A1.27 (GPIO21); also elsewhere on the board
unnamed 66: A1.29 (GPIO22); also elsewhere on the board

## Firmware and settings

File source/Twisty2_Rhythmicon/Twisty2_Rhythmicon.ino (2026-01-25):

// Copyright 2026 Rich Heslip
//
// Author: Rich Heslip 
//
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
// See http://creativecommons.org/licenses/MIT/ for more information.
//
// -----------------------------------------------------------------------------
/*
 * MIDI sequencer using RP2040
 * uses 16 multiplexed encoders for step data input
 * a separate encoder for menu inputs
 * Graphics and text UI is processed on core 0, sequencer clocking and MIDI processed by core 1
 * Jan 2026 - implemented a Subharmonicon like sequencer from the Twisty 2 code and the one I wrote for the Teensy 4
 */



#include <Arduino.h>
#include <Wire.h>
#include <Adafruit_GFX.h>
#include <Adafruit_SSD1306.h>
#include <Adafruit_TinyUSB.h>
#include <MIDI.h>
#include "Clickencoder.h"
#include <Adafruit_NeoPixel.h>
#include <Control_Surface.h>

// BT MIDI works (with the exception of note messages) on the Twisty2 app but does not work here. maybe because I'm using both cores?
#define BLUETOOTH  // define for bluetooth MIDI 
#ifdef BLUETOOTH
#include <MIDI_Interfaces/BluetoothMIDI_Interface.hpp>
#endif


#define TRUE 1
#define FALSE 0

// I used mostly int16 types - its what the menu requires and the compiler seems to deal with basic conversions

//int16_t steps = 8; // initial number of steps


// graphical editing UI states - UI logic assumes an init state and an edit state for each
// text parameter editing system has its own state machine for historical reasons
// the text menu system requires parameters to be 16 bit integers which is why most of the data types are int16

enum UISTATES {RUN,DISPLAYOFF,DISPLAYON};
int16_t UI_state=RUN; // initial UI state
bool menumode=0;  // when true we are in the text menu system

#define BATTERY_SCALE 3300*2/1024  // 3.3v reference, 10 bit A/D with external 2:1 divider. * 1000 so menus can display as a float
#define BATVOLTAGE 28  // battery voltage input 
int16_t batteryvoltage; // integer but displayed as a float in menus

#define DEFAULT_VELOCITY 120
#define NTRACKS 3 // number of sequencer tracks - each track has notes, gates etc
#define NUM_CLOCKS 4
#define SEQ_STEPS 4 // 4 step sequencer
int16_t current_track=0; // track we are editing
int16_t MIDIinputchannel[NTRACKS] = {1,2,3}; // midi channel to use for sequencer notes
int16_t MIDIoutputchannel[NTRACKS] = {1,2,3}; // midi channel to use for sequencer notes
int16_t trackenabled[NTRACKS] = {1,1,1}; // 1 if track on is 1, 0 if off

#define MAX_DIVIDER 128  // maximum clock divider
bool rhythmclks[NTRACKS+1][NUM_CLOCKS]= {1,0,0,0,0,0,0,0,0,0,0,0,1,1,1,1}; // 1 to enable clock source to track. last 4 are always set to show divider LEDs

const char * notenames[]={"C","C#","D","D#","E","F","F#","G","G#","A","A#","B","C"};

#define DISPLAY_BLANK_MS 120*1000  // display blanking time
int32_t displaytimer ; // display blanking timer

#define TEMPO    120  // startup tempo
#define PPQN 24  // clocks per quarter note
#define PPQN_DIV 6 // divider for 16th notes
#define GATE_DIV 3  // gate time is half the note duration
#define MIDDLE_C 60 // MIDI note used as default sequencer value and as a base for incoming MIDI offsets

int16_t bpm = TEMPO;
int32_t lastMIDIclock; // timestamp of last MIDI clock
int16_t MIDIclocks=PPQN*2; // midi clock counter
int16_t MIDIsync = 16;  // number of clocks required to sync BPM
int16_t useMIDIclock = 0; // true if we are using MIDI clock

enum CONTROLSTATES {IDLE,STARTUP,RUNNING,RUNJUSTSYNCED,SHUTDOWN}; // control state machine states
int16_t controlstate=RUNNING; // state machine state

#define PIN_WIRE_SDA 2
#define PIN_WIRE_SCL 3
#define LEDPIN 4

#define NUMPIXELS 16 // 
#define LED_RED 0x1f0000  // only using 5 bits to keep LEDs from getting too bright
#define LED_GREEN 0x001f00
#define LED_BLUE 0x00001f
#define LED_ORANGE (LED_RED|LED_GREEN)
#define LED_VIOLET (LED_RED|LED_BLUE)
#define LED_AQUA (LED_GREEN|LED_BLUE)
#define LED_BLACK 0
#define LED_WHITE (LED_RED|LED_GREEN|LED_BLUE)

int32_t divcolors[NUM_CLOCKS]={LED_RED,LED_GREEN,LED_AQUA,LED_VIOLET}; // colors indicate which clock divider is in use

Adafruit_NeoPixel LEDS(NUMPIXELS, LEDPIN, NEO_GRB + NEO_KHZ800);

// sequencer object
//StepSeq seq = StepSeq(128);

#define NUMENCODERS 16 // number of encoders

// I/O definitions
#define A_MUX_0 9   // HC4067 address lines
#define A_MUX_1 8
#define A_MUX_2 7
#define A_MUX_3 6

#define ENCA_IN 17 // ports we read values from MUX
#define ENCB_IN 11 // A & B swapped to get correct rotation
#define ENCSW_IN 10

#define LMENU_ENCA_IN 19 // left menu encoder
#define LMENU_ENCB_IN 18 // A & B swapped to get correct rotation
#define LMENU_ENCSW_IN 16

#define RMENU_ENCA_IN 22 // left menu encoder
#define RMENU_ENCB_IN 21 // A & B swapped to get correct rotation
#define RMENU_ENCSW_IN 20

//#define START_STOP_BUTTON 5  // start/stop button
//#define SHIFT_BUTTON 28      // UI function shift button

// encoders - use an array of clickencoder objects for the 16 multiplexed encoders
#define ENCDIVIDE 4  // divide by 4 works best with my encoders
ClickEncoder enc[NUMENCODERS] = {
  ClickEncoder(ENCA_IN,ENCB_IN,ENCSW_IN,ENCDIVIDE), 
  ClickEncoder(ENCA_IN,ENCB_IN,ENCSW_IN,ENCDIVIDE), 
  ClickEncoder(ENCA_IN,ENCB_IN,ENCSW_IN,ENCDIVIDE), 
  ClickEncoder(ENCA_IN,ENCB_IN,ENCSW_IN,ENCDIVIDE),
  ClickEncoder(ENCA_IN,ENCB_IN,ENCSW_IN,ENCDIVIDE), 
  ClickEncoder(ENCA_IN,ENCB_IN,ENCSW_IN,ENCDIVIDE), 
  ClickEncoder(ENCA_IN,ENCB_IN,ENCSW_IN,ENCDIVIDE), 
  ClickEncoder(ENCA_IN,ENCB_IN,ENCSW_IN,ENCDIVIDE),
  ClickEncoder(ENCA_IN,ENCB_IN,ENCSW_IN,ENCDIVIDE), 
  ClickEncoder(ENCA_IN,ENCB_IN,ENCSW_IN,ENCDIVIDE), 
  ClickEncoder(ENCA_IN,ENCB_IN,ENCSW_IN,ENCDIVIDE), 
  ClickEncoder(ENCA_IN,ENCB_IN,ENCSW_IN,ENCDIVIDE),
  ClickEncoder(ENCA_IN,ENCB_IN,ENCSW_IN,ENCDIVIDE), 
  ClickEncoder(ENCA_IN,ENCB_IN,ENCSW_IN,ENCDIVIDE), 
  ClickEncoder(ENCA_IN,ENCB_IN,ENCSW_IN,ENCDIVIDE), 
  ClickEncoder(ENCA_IN,ENCB_IN,ENCSW_IN,ENCDIVIDE)
};


ClickEncoder lmenuenc(LMENU_ENCA_IN,LMENU_ENCB_IN,LMENU_ENCSW_IN,ENCDIVIDE); // left menu encoder object
ClickEncoder rmenuenc(RMENU_ENCA_IN,RMENU_ENCB_IN,RMENU_ENCSW_IN,ENCDIVIDE); // right menu encoder object

#define OLED_DISPLAY   // for graphics conditionals

#define OLED_RESET -1        // Reset pin # (or -1 if sharing Arduino reset pin)
#define SCREEN_ADDRESS 0x3C  ///< See datasheet for Address; 0x3D for 128x64, 0x3C for 128x32
#define SCREEN_WIDTH 128  // OLED display width, in pixels
#define SCREEN_HEIGHT 32  // OLED display height, in pixels
#define SCREEN_BUFFER_SIZE (SCREEN_WIDTH * ((SCREEN_HEIGHT + 7) / 8))

Adafruit_SSD1306 display(SCREEN_WIDTH, SCREEN_HEIGHT, &Wire1, OLED_RESET);


// use Control Surface MIDI
USBMIDI_Interface usbMIDI;

HardwareSerialMIDI_Interface serialMIDI {Serial1, MIDI_BAUD};

#ifdef BLUETOOTH
// Instantiate a MIDI over BLE interface
BluetoothMIDI_Interface bleMIDI;
#endif

#define TIMER_MICROS 1000 // interrupt period

// RP2040 timer code from https://github.com/raspberrypi/pico-examples/blob/master/timer/timer_lowlevel/timer_lowlevel.c
// Use alarm 0
#define ALARM_NUM 0
#define ALARM_IRQ timer_hardware_alarm_get_irq_num(timer_hw, ALARM_NUM)

static void alarm_in_us(uint32_t delay_us) {
  hw_set_bits(&timer_hw->inte, 1u << ALARM_NUM);
  irq_set_exclusive_handler(ALARM_IRQ, alarm_irq);
  irq_set_enabled(ALARM_IRQ, true);
  alarm_in_us_arm(delay_us);
}

static void alarm_in_us_arm(uint32_t delay_us) {
  uint64_t target = timer_hw->timerawl + delay_us;
  timer_hw->alarm[ALARM_NUM] = (uint32_t) target;
}

// timer interrupt handler
// scans thru the multiplexed encoders and handles the menu encoders

static void alarm_irq(void) {
  for (int addr=0; addr< NUMENCODERS;++addr) {
    digitalWrite(A_MUX_0, addr & 1);
    digitalWrite(A_MUX_1, addr & 2);
    digitalWrite(A_MUX_2, addr & 4);
    digitalWrite(A_MUX_3, addr & 8); 
    delayMicroseconds(4);         // address settling time 
    enc[addr].service();    // check the encoder inputs
  } 
  lmenuenc.service(); // handle the menu encoders which are on different port pins
  rmenuenc.service(); // 
  hw_clear_bits(&timer_hw->intr, 1u << ALARM_NUM); // clear IRQ flag
  alarm_in_us_arm(TIMER_MICROS);  // reschedule interrupt
}


// turn off the display to avoid burn in but keep the display buffer intact
// the next call to display.display() will automagically restore what was there plus whatver has been drawn since

void blankdisplay(void) {
  uint8_t tempbuf[SCREEN_BUFFER_SIZE];
  uint8_t * buf, * tbuf;
  buf=display.getBuffer();
  tbuf= tempbuf;
  memcpy(tbuf,buf,SCREEN_BUFFER_SIZE); // copy frame buffer to temp storage
  display.clearDisplay();
  display.display();  // turn off the OLEDs
  memcpy(buf,tbuf,SCREEN_BUFFER_SIZE); // restore the old frame buffer
}

// update the display and reset the display blanking timer
void updatedisplay(){
  display.display();
  displaytimer=millis();
}


// midi related stuff - after initialization all MIDI stuff runs on core1 for timing accuracy
// splitting it across both cores causes MidiUSB to hang eventually

void sendnoteOn(uint8_t channel,uint8_t pitch, uint8_t velocity) {
  MIDIAddress midiaddress ={pitch,Channel_1 + (channel-1)}; // control surface library requires this form of MIDI addressing -I'm not a fan of the design but its the only Arduino BLE MIDI library I could find
  usbMIDI.sendNoteOn(midiaddress, velocity);
  serialMIDI.sendNoteOn(midiaddress, velocity);
#ifdef BLUETOOTH
  bleMIDI.sendNoteOn(midiaddress, velocity);
#endif
}

void sendnoteOff(uint8_t channel, uint8_t pitch,uint8_t velocity) {
  MIDIAddress midiaddress= {pitch,Channel_1 + (channel-1)};
  usbMIDI.sendNoteOff(midiaddress, velocity);
  serialMIDI.sendNoteOff(midiaddress, velocity);
#ifdef BLUETOOTH
  bleMIDI.sendNoteOff(midiaddress, velocity);
#endif
}

// message 0x0B control change.
// 2nd parameter is the control number number (0-119).
// 3rd parameter is the control value (0-127).

void sendcontrolChange(uint8_t channel, uint8_t control, uint8_t value) {
  MIDIAddress midiaddress= {control,Channel_1 + (channel-1)};  
  usbMIDI.sendControlChange(midiaddress, value); 
  serialMIDI.sendControlChange(midiaddress, value); 
#ifdef BLUETOOTH
  bleMIDI.sendControlChange(midiaddress, value); 
#endif
}

// message program change.
// 2nd parameter is the PC value (0-127).

void sendprogramChange(uint8_t channel, uint8_t value) {
  MIDIAddress midiaddress= {value,Channel_1 + (channel-1)};  // confusing way of sending MIDI messages
  usbMIDI.sendProgramChange(midiaddress); 
  serialMIDI.sendProgramChange(midiaddress); 
#ifdef BLUETOOTH
  bleMIDI.sendProgramChange(midiaddress); 
#endif
}


// set up as include files because I'm too lazy to create proper header and .cpp files
#include "scales.h"   //
#include "seq.h"   // has to come after midi note on/of
#include "menusystem.h"  // has to come after display and encoder objects creation
#include "MIDIcallbacks.h"

// these functions are here to avoid forward references. should really do proper include files!



// flush all encoder messages 
// pending messages cause race conditions in the menus sometimes 
void flush_encoders(void) {
  ClickEncoder::Button button;
  ClickEncoder::ButtonEvent event;  
  for (int i=0;i<NUMENCODERS;++i) {  
    enc[i].getButton();
    enc[i].getButtonEvent();
    enc[i].getValue();
  }
  lmenuenc.getButton();
  lmenuenc.getButtonEvent();
  lmenuenc.getValue();
  rmenuenc.getButton();
  rmenuenc.getButtonEvent();
  rmenuenc.getValue();
}

// display rhythm divider value on OLED
void showrhythm(int16_t r){
  display.setCursor(SCREENWIDTH/NUM_CLOCKS*r,24);
  display.print("     ");
  display.setCursor(SCREENWIDTH/NUM_CLOCKS*r,24);
  display.printf("/%d",rhythm[r].divider);
  updatedisplay();  
}

// show all rhythm dividers
void showrhythms(void) {
  for (int16_t i=0; i< NUM_CLOCKS;++i) showrhythm(i);
}

// show note value on OLED
void shownote(int16_t track, int16_t index){
  display.setCursor(SCREENWIDTH/SEQ_STEPS*index,track*8); 
  display.print("     ");
  display.setCursor(SCREENWIDTH/SEQ_STEPS*index,track*8); 
  int16_t notenumber=constrain(quantize(notes[track].val[index]+notes[track].root,scales[notes[track].scale],notes[track].root),0,127);
 // Serial.printf("track %d index %d notenumber %d note %d octave %d\n",track,index, notenumber,notenumber%12,notenumber/12-2);
  display.printf("%s%d",notenames[notenumber%12],notenumber/12-2); 
  updatedisplay();   
}

// show all note values on OLED
void shownotes(void){
  for (int16_t track=0; track< NTRACKS;++track)
    for (int16_t step=0; step< SEQ_STEPS;++step) shownote(track,step);
}

// show LED color for encoder - this depends on what's clocking it
// last 4 encoders are the clock dividers so their LEDs are always on

void showLED(int16_t enc) {
  if (rhythmclks[enc/NUM_CLOCKS][enc%NUM_CLOCKS]) LEDS.setPixelColor(enc,divcolors[enc%NUM_CLOCKS]);
  else LEDS.setPixelColor(enc,LED_BLACK);
}

// update all LEDs
void showLEDs(void) {
  for (int16_t i=0; i< NUMENCODERS;++i) showLED(i);
}

void fatalerror(const char * errorstring){
  display.clearDisplay();
  display.setTextSize(1);
  display.setCursor(0,0);
  display.printf("FATAL ERROR\n\n%s", errorstring);
  updatedisplay();

  while (1) {
    for (int16_t i=0;i<NUMENCODERS;++i) LEDS.setPixelColor(i,LED_RED); // flashing red
    LEDS.show();
    delay(75);
    for (int16_t i=0;i<NUMENCODERS;++i) LEDS.setPixelColor(i,LED_BLACK); // 
    LEDS.show();
    delay(75);
  } 
}

void setup() {
  Serial.begin(115200);

// init IO ports
  pinMode(A_MUX_0, OUTPUT);    // encoder mux addresses
  pinMode(A_MUX_1, OUTPUT);  
  pinMode(A_MUX_2, OUTPUT);  
  pinMode(A_MUX_3, OUTPUT);
  pinMode(LMENU_ENCA_IN, INPUT_PULLUP);  // menu encoder and switches
  pinMode(LMENU_ENCB_IN, INPUT_PULLUP);    
  pinMode(LMENU_ENCSW_IN, INPUT_PULLUP); 
  pinMode(RMENU_ENCA_IN, INPUT_PULLUP);  // menu encoder and switches
  pinMode(RMENU_ENCB_IN, INPUT_PULLUP);    
  pinMode(RMENU_ENCSW_IN, INPUT_PULLUP); 

// set up I2C pins - meant to use I2C0 controller but messed up the schematic pins so have to use I2C1
  Wire1.setSDA(PIN_WIRE_SDA);
  Wire1.setSCL(PIN_WIRE_SCL);
  Wire1.begin();

// set up timer interrupt 
  alarm_in_us(TIMER_MICROS);
 
  LEDS.begin(); // INITIALIZE NeoPixel strip object (REQUIRED)
  LEDS.show();

  // SSD1306_SWITCHCAPVCC = generate display voltage from 3.3V internally
  if(!display.begin(SSD1306_SWITCHCAPVCC, SCREEN_ADDRESS)) {
    Serial.println(F("SSD1306 allocation failed"));
    fatalerror(""); // Don't proceed, loop forever
  }
  display.setRotation(2);
  display.clearDisplay();
  display.setTextSize(1);

	display.setTextColor(WHITE,BLACK); // foreground, background  
  display.setCursor(16,10);
  display.printf("PicoRhythmicon\n"); // power on message
  display.display();
  delay(3000);

 // display.setTextSize(1);

#ifdef BLUETOOTH
  bleMIDI.setName("PicoRythmicon");
#endif

  MIDI_Interface::beginAll();


  displaytimer=millis(); // reset display blanking timer

  showLEDs(); // show startup LED state
  shownotes();
  showrhythms();

  // attach MIDI message handler functions
  usbMIDI.setCallbacks(callback); // Attach the custom callbacks
  bleMIDI.setCallbacks(callback); // Attach the custom callbacks

}

// first Pico core does UI etc - not super time critical
void loop() {
  
  ClickEncoder::Button button;
  int16_t encvalue,edited_step,edited_val;

  if ((millis()-displaytimer) > DISPLAY_BLANK_MS) {
    UI_state=DISPLAYOFF;  // 
  } 

  if (menumode) {  // in menu mode we just loop here doing menus - a bit kludgy

    domenus();  // call the text menu state machine
    batteryvoltage=analogRead(BATVOLTAGE)*BATTERY_SCALE; // update the battery voltage
    if ((lmenuenc.getButton() == ClickEncoder::Clicked) || (rmenuenc.getButton() == ClickEncoder::DoubleClicked) ) { // exit menu mode
      UI_state=RUN; // exiting text menus so force a redraw
      menumode=FALSE;
      display.clearDisplay();
      shownotes();
      showrhythms();
      flush_encoders();   // toss any encoder messages to avoid race conditions
    }
//    displaytimer=millis(); // reset display blanking timer so menus don't blank
  }
  
 if (!menumode) {  // do the UI state machine

    if (rmenuenc.getButton() == ClickEncoder::Clicked) { // enter menu mode
      display.fillScreen(BLACK); // erase screen
      topmenuindex=0; // 
      topmenu[topmenuindex].submenuindex=0;  // start from the first item
      drawsubmenus();
      drawselector(topmenu[topmenuindex].submenuindex);
      updatedisplay();
      flush_encoders();   // toss any encoder messages
      menumode=TRUE; // shift button toggles onscreen menus
      UI_state=DISPLAYON; // because we will fall into the UI state machine below
    }

// UI state machine
    switch (UI_state) {
      case RUN:  // core 0 running UI, display on
        break; 
      case DISPLAYON: // display was blanked, redraw
        display.display(); 
        UI_state=RUN;
        break;
      case DISPLAYOFF: // display timed out, blank display
        blankdisplay(); 
        UI_state=RUN;
        break;
      

      default:
        UI_state = RUN;
    }
/*
    if (encvalue=lmenuenc.getValue()) { // scroll thru UI pages
      displaytimer=millis(); // reset display blanking timer
      if (!digitalRead(LMENU_ENCSW_IN)) { // button value not working for some reason
        current_track+=encvalue;
        current_track=constrain(current_track,0,NTRACKS-1); // handle wrap around
        UI_state=UIpages[UIpage]; // forces redraw
      }
      else {
        UIpage+=encvalue;  // next page
        UIpage=constrain(UIpage,0,NUMUIPAGES-1); // handle wrap around
        UI_state=UIpages[UIpage];
      //Serial.printf("encvalue= %d UIpage=%d UI_state=%d\n",encvalue,UIpage,UI_state);
      }
    }
*/
    button = lmenuenc.getButton();
    if (button == ClickEncoder::Clicked) { // toggle play/stop
      if (controlstate == RUNNING) controlstate=IDLE;  // this core writes, other core only reads - multicore safe
      else controlstate= RUNNING;
      UI_state=DISPLAYON; // redraw screen if it was blanked
    }

    if (button == ClickEncoder::DoubleClicked) { // sync sequencers
      rp2040.fifo.push(0);  // send a sync message to other core which runs sequencers
      UI_state=DISPLAYON; // redraw screen if it was blanked
    }

    for (int16_t trk=0; trk< NTRACKS; ++trk) { // encoder buttons enable and disable clock sources
      for (int16_t clk=0; clk< NUM_CLOCKS; ++clk) { 
        int16_t index=trk*NUM_CLOCKS +clk;
        button = enc[index].getButton();
        if (button == ClickEncoder::Clicked) { // toggle clock source on/off
          if (rhythmclks[trk][clk]) rhythmclks[trk][clk]=0; 
          else rhythmclks[trk][clk]=1;
          showLED(index);  // update LED state too
          UI_state=DISPLAYON; // redraw screen if it was blanked
        }
        int16_t val;
        if ((val=enc[index].getValue()) !=0) { // change note values if encoders changed
          notes[trk].val[clk]=constrain(notes[trk].val[clk]+val,-24,24); // allow 2 octave range
          shownote(trk,clk);
          UI_state=DISPLAYON; // redraw screen if it was blanked
          
        }
      }
    }
    for (int16_t i=NTRACKS*NUM_CLOCKS; i< NUMENCODERS;++i) { // last 4 encoders set clock dividers
      int16_t val;
      if ((val=enc[i].getValue()) !=0) { // change clock dividers if encoder changed
        rhythm[i%NUM_CLOCKS].divider=constrain(rhythm[i%NUM_CLOCKS].divider-val,1,MAX_DIVIDER); // divider range is 1-16, CCW increases divider as on SubHarmonicon
        showrhythm(i%NUM_CLOCKS);
        UI_state=DISPLAYON; // redraw screen if it was blanked
      }
    }
  }

}

// second core setup
// second core dedicated to clock and MIDI processing
void setup1() {
  delay (1000); // wait for main core to start up peripherals

}

// second core dedicated to clocks and note on/off for timing accuracy - graphical UI causes redraw delays etc
// implemented as a simple state machine
// start button toggles sequencers on and off
// shift + start button resyncs sequencers
void loop1(){

  LEDS.show(); // update LED display

  MIDI_Interface::updateAll(); // Update the Control Surface MIDI interfaces

// multicore safe messages from core1 to core2 via the fifo

  while (rp2040.fifo.available()) { // get MIDI command, channel# = voice#
    rp2040.fifo.pop(); // only one command - sync
    sync_sequencers();
    showLEDs();  // update LEDs which probably changed
  }

  if (controlstate==RUNNING) do_clocks();

}

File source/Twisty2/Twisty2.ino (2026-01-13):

// Copyright 2023 Rich Heslip
//
// Author: Rich Heslip 
//
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
// See http://creativecommons.org/licenses/MIT/ for more information.
//
// -----------------------------------------------------------------------------
/*
 * Twisty 2 MIDI controller using RP2040 or RP2350
 * uses 16 multiplexed encoders for encoder and button input with RGB LEDs
 * two encoders for menu inputs
 * I2C OLED display
 * R Heslip Dec 2025 
 * based on my Twisty MIDI controller code and other stuff
 * 
 */


#include <Arduino.h>
#include <Wire.h>
#include <Adafruit_GFX.h>
#include <Adafruit_SSD1306.h>
#include <Adafruit_TinyUSB.h>  
#include <MIDI.h>
#include "Clickencoder.h"
//#include "StepSeq.h"
#include <Adafruit_NeoPixel.h>
#include <ArduinoJson.h>
#include "LittleFS.h"
#include <Control_Surface.h>

#define BLUETOOTH  // define for bluetooth MIDI - you MUST set up IPV4 + Bluetooth stack in the arduino Tools menu
#ifdef BLUETOOTH
#include <MIDI_Interfaces/BluetoothMIDI_Interface.hpp>
#endif

#define TRUE 1
#define FALSE 0

#define PIN_WIRE_SDA 2
#define PIN_WIRE_SCL 3
#define LEDPIN 4

#define NUMPIXELS 16 // 
#define LED_RED 0x1f0000  // only using 5 bits to keep LEDs from getting too bright
#define LED_GREEN 0x001f00
#define LED_BLUE 0x00001f
#define LED_ORANGE (LED_RED|LED_GREEN)
#define LED_VIOLET (LED_RED|LED_BLUE)
#define LED_AQUA (LED_GREEN|LED_BLUE)
#define LED_BLACK 0
#define LED_WHITE (LED_RED|LED_GREEN|LED_BLUE)

int32_t colorpalette[8]={LED_RED,LED_ORANGE,LED_GREEN,LED_AQUA,LED_BLUE,LED_VIOLET,LED_WHITE,LED_BLACK}; // limited color palette makes things easier

int8_t brightness_table[32] ={  // more or less exponential table to compensate for perceived brightness
  1,1,2,2,
  3,3,4,4,
  6,6,8,8,
  12,12,16,16,
  25,25,34,34,
  44,44,58,58,
  72,72,96,96,
  110,110,127,127
};

Adafruit_NeoPixel LEDS(NUMPIXELS, LEDPIN, NEO_GRB + NEO_KHZ800);

#define OLED_RESET -1        // Reset pin # (or -1 if sharing Arduino reset pin)
#define SCREEN_ADDRESS 0x3C  ///< See datasheet for Address; 0x3D for 128x64, 0x3C for 128x32
#define SCREEN_WIDTH 128  // OLED display width, in pixels
#define SCREEN_HEIGHT 32  // OLED display height, in pixels
#define SCREEN_BUFFER_SIZE (SCREEN_WIDTH * ((SCREEN_HEIGHT + 7) / 8))
Adafruit_SSD1306 display(SCREEN_WIDTH, SCREEN_HEIGHT, &Wire1, OLED_RESET);

#define DISPLAY_BLANK_MS 120*1000  // display blanking time
#define LEDFLASH_EDIT  250   // LED flash while editing
int32_t displaytimer ; // display blanking timer
int32_t LEDtimer; // LED flash timer
bool LEDstate;   // for LED flash
#define OLED_DISPLAY   // for graphics conditionals

#define NUMENCODERS 16 // number of encoders

// I/O definitions
#define A_MUX_0 9   // HC4067 address lines
#define A_MUX_1 8
#define A_MUX_2 7
#define A_MUX_3 6

#define ENCA_IN 17 // ports we read values from MUX
#define ENCB_IN 11 // A & B swapped to get correct rotation
#define ENCSW_IN 10

#define LMENU_ENCA_IN 19 // left menu encoder
#define LMENU_ENCB_IN 18 // A & B swapped to get correct rotation
#define LMENU_ENCSW_IN 16

#define RMENU_ENCA_IN 22 // left menu encoder
#define RMENU_ENCB_IN 21 // A & B swapped to get correct rotation
#define RMENU_ENCSW_IN 20

// encoders - use an array of clickencoder objects for the 16 multiplexed encoders
#define ENCDIVIDE 4  // divide by 4 works best with my encoders
ClickEncoder enc[NUMENCODERS] = {
  ClickEncoder(ENCA_IN,ENCB_IN,ENCSW_IN,ENCDIVIDE), 
  ClickEncoder(ENCA_IN,ENCB_IN,ENCSW_IN,ENCDIVIDE), 
  ClickEncoder(ENCA_IN,ENCB_IN,ENCSW_IN,ENCDIVIDE), 
  ClickEncoder(ENCA_IN,ENCB_IN,ENCSW_IN,ENCDIVIDE),
  ClickEncoder(ENCA_IN,ENCB_IN,ENCSW_IN,ENCDIVIDE), 
  ClickEncoder(ENCA_IN,ENCB_IN,ENCSW_IN,ENCDIVIDE), 
  ClickEncoder(ENCA_IN,ENCB_IN,ENCSW_IN,ENCDIVIDE), 
  ClickEncoder(ENCA_IN,ENCB_IN,ENCSW_IN,ENCDIVIDE),
  ClickEncoder(ENCA_IN,ENCB_IN,ENCSW_IN,ENCDIVIDE), 
  ClickEncoder(ENCA_IN,ENCB_IN,ENCSW_IN,ENCDIVIDE), 
  ClickEncoder(ENCA_IN,ENCB_IN,ENCSW_IN,ENCDIVIDE), 
  ClickEncoder(ENCA_IN,ENCB_IN,ENCSW_IN,ENCDIVIDE),
  ClickEncoder(ENCA_IN,ENCB_IN,ENCSW_IN,ENCDIVIDE), 
  ClickEncoder(ENCA_IN,ENCB_IN,ENCSW_IN,ENCDIVIDE), 
  ClickEncoder(ENCA_IN,ENCB_IN,ENCSW_IN,ENCDIVIDE), 
  ClickEncoder(ENCA_IN,ENCB_IN,ENCSW_IN,ENCDIVIDE)
};

ClickEncoder lmenuenc(LMENU_ENCA_IN,LMENU_ENCB_IN,LMENU_ENCSW_IN,ENCDIVIDE); // left menu encoder object
ClickEncoder rmenuenc(RMENU_ENCA_IN,RMENU_ENCB_IN,RMENU_ENCSW_IN,ENCDIVIDE); // right menu encoder object

// use Control Surface MIDI
USBMIDI_Interface usbMIDI;

HardwareSerialMIDI_Interface serialMIDI {Serial1, MIDI_BAUD};

#ifdef BLUETOOTH
// Instantiate a MIDI over BLE interface
BluetoothMIDI_Interface bleMIDI;
#endif

#define BASE_CC 16  // lowest default CC number to use
#define DEFAULT_VELOCITY 127
#define CONTROLLER_PAGES 4  // number of pages
#define DEFAULT_ENCODER_CHANNEL 1  // default MIDI channel for encoders
#define DEFAULT_SWITCH_CHANNEL 2  // default MIDI channel for encoders
uint16_t page=0; // CC page 0-3
uint8_t lastnotesent=0; // keeps track of last note sent when switch sends note messages
bool displaySwitchLEDs;    // toggle to show switch or encoder states
enum encodertypes {CCTYPE};
enum switchmodes {MOMENTARY,TOGGLE};
enum switchtypes {CCMESSAGE,PCMESSAGE,NOTEMESSAGE,SETENC};

struct controllerencoder {
  int16_t type;   // midi message type
  int16_t channel;
  int16_t ccnumber;
  int16_t minvalue;
  int16_t maxvalue;
  int16_t value;
  int16_t colorindex;  // index into color lookup table leds are 8 bits R, G and B
  int16_t labelindex; // index of label
};

struct controllerswitch {
  int16_t mode;
  int16_t type;
  int16_t channel;
  int16_t ccnumber;
  int16_t minvalue;
  int16_t maxvalue;
  int16_t value;
  int16_t colorindex;
  int16_t labelindex; // index of label
};

struct controllerpage {
  struct controllerencoder encoder[NUMENCODERS];
  struct controllerswitch encswitch[NUMENCODERS];
} controls[CONTROLLER_PAGES];

// edit buffer
struct controller {
  struct controllerencoder encoder;
  struct controllerswitch encswitch;
} editbuffer;
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

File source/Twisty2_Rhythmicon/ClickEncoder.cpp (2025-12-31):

// ----------------------------------------------------------------------------
// Rotary Encoder Driver with Acceleration
// Supports Click, DoubleClick, Long Click
//
// (c) 2010 karl@pitrich.com
// (c) 2014 karl@pitrich.com
//
// Timer-based rotary encoder logic by Peter Dannegger
// http://www.mikrocontroller.net/articles/Drehgeber
// ----------------------------------------------------------------------------
// RH added button edge events which are needed sometimes Dec 2025

#include "ClickEncoder.h"

// ----------------------------------------------------------------------------
// Button configuration (values for 1ms timer service calls)
//
#define ENC_BUTTONINTERVAL    10  // check button every x milliseconds, also debouce time
#define ENC_DOUBLECLICKTIME  800  // second click within 00ms
#define ENC_HOLDTIME        500  // report held button after .5s

// ----------------------------------------------------------------------------
// Acceleration configuration (for 1000Hz calls to ::service())
//
#define ENC_ACCEL_TOP      3072   // max. acceleration: *12 (val >> 8)
#define ENC_ACCEL_INC        50
#define ENC_ACCEL_DEC         2

// ----------------------------------------------------------------------------

#if ENC_DECODER != ENC_NORMAL
#  ifdef ENC_HALFSTEP
     // decoding table for hardware with flaky notch (half resolution)
     const int8_t ClickEncoder::table[16] __attribute__((__progmem__)) = {
       0, 0, -1, 0, 0, 0, 0, 1, 1, 0, 0, 0, 0, -1, 0, 0
     };
#  else
     // decoding table for normal hardware
     const int8_t ClickEncoder::table[16] __attribute__((__progmem__)) = {
       0, 1, -1, 0, -1, 0, 0, 1, 1, 0, 0, -1, 0, -1, 1, 0
     };
#  endif
#endif

// ----------------------------------------------------------------------------

ClickEncoder::ClickEncoder(uint8_t A, uint8_t B, uint8_t BTN, uint8_t stepsPerNotch, bool active)
  : doubleClickEnabled(true), accelerationEnabled(true),
    delta(0), last(0), acceleration(0),
    button(Open), steps(stepsPerNotch),
    pinA(A), pinB(B), pinBTN(BTN), pinsActive(active)
{
  uint8_t configType = (pinsActive == LOW) ? INPUT_PULLUP : INPUT;
  pinMode(pinA, configType);
  pinMode(pinB, configType);
  pinMode(pinBTN, configType);

  if (digitalRead(pinA) == pinsActive) {
    last = 3;
  }

  if (digitalRead(pinB) == pinsActive) {
    last ^=1;
  }
}

// ----------------------------------------------------------------------------
// call this every 1 millisecond via timer ISR
//
void ClickEncoder::service(void)
{
  bool moved = false;
  unsigned long now = millis();

  if (accelerationEnabled) { // decelerate every tick
    acceleration -= ENC_ACCEL_DEC;
    if (acceleration & 0x8000) { // handle overflow of MSB is set
      acceleration = 0;
    }
  }

#if ENC_DECODER == ENC_FLAKY
  last = (last << 2) & 0x0F;

  if (digitalRead(pinA) == pinsActive) {
    last |= 2;
  }

  if (digitalRead(pinB) == pinsActive) {
    last |= 1;
  }

  uint8_t tbl = pgm_read_byte(&table[last]);
  if (tbl) {
    delta += tbl;
    moved = true;
  }
#elif ENC_DECODER == ENC_NORMAL
  int8_t curr = 0;

  if (digitalRead(pinA) == pinsActive) {
    curr = 3;
  }

  if (digitalRead(pinB) == pinsActive) {
    curr ^= 1;
  }

  int8_t diff = last - curr;

  if (diff & 1) {            // bit 0 = step
    last = curr;
    delta += (diff & 2) - 1; // bit 1 = direction (+/-)
    moved = true;
  }
#else
# error "Error: define ENC_DECODER to ENC_NORMAL or ENC_FLAKY"
#endif

  if (accelerationEnabled && moved) {
    // increment accelerator if encoder has been moved
    if (acceleration <= (ENC_ACCEL_TOP - ENC_ACCEL_INC)) {
      acceleration += ENC_ACCEL_INC;
    }
  }

  // handle button
  //
#ifndef WITHOUT_BUTTON
  if (pinBTN > 0 // check button only, if a pin has been provided
      && (now - lastButtonCheck) >= ENC_BUTTONINTERVAL) // checking button is sufficient every 10-30ms
  {
    lastButtonCheck = now;


// RH added events that flag button activating and deactivating
    if ((digitalRead(pinBTN) == pinsActive) && !edge) { // event - key has just activated
      edge=1;
      event=ActiveEdge;
    }

    if ((digitalRead(pinBTN) == !pinsActive) && edge) { // event - key has just deactivated
      edge=0;
      event=InActiveEdge;
    }

    if (digitalRead(pinBTN) == pinsActive) { // key is down
      button=Closed;
      keyDownTicks++;
      if (keyDownTicks > (ENC_HOLDTIME / ENC_BUTTONINTERVAL)) {
        button = Held;
      }
    }

    if (digitalRead(pinBTN) == !pinsActive) { // key is now up
      if (keyDownTicks /*> ENC_BUTTONINTERVAL*/) {
        if (button == Held) {
          button = Released;
          doubleClickTicks = 0;
        }
        else {
#define ENC_SINGLECLICKONLY 1
          if (doubleClickTicks > ENC_SINGLECLICKONLY) {   // prevent trigger in single click mode
            if (doubleClickTicks < (ENC_DOUBLECLICKTIME / ENC_BUTTONINTERVAL)) {
              button = DoubleClicked;
              doubleClickTicks = 0;
            }
          }
          else {
            doubleClickTicks = (doubleClickEnabled) ? (ENC_DOUBLECLICKTIME / ENC_BUTTONINTERVAL) : ENC_SINGLECLICKONLY;
          }
        }
      }

      keyDownTicks = 0;
    }

    if (doubleClickTicks > 0) {
      doubleClickTicks--;
      if (--doubleClickTicks == 0) {
        button = Clicked;
      }
    }
  }
#endif // WITHOUT_BUTTON

}

// ----------------------------------------------------------------------------
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

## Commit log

2026-01-05 Updated source code and added .STL files
    Updated to latest source and added enclosure .STL files
    [Pico MIDIController Base.stl, Pico MIDIcontroller Top.stl]
2026-01-13 Changed to Control Surface MIDI
    changed all the MIDI interfaces to use the Control Surface Library. This fixed the bug in ble MIDI send note on/off. Fixed encoder structure initialization bug, made the MID interface names more consistent
    [Twisty2.ino]
2026-01-13 fixed include file for no bluetooth compile
    fixed include files - would not have compiled without bluetooth
    [Twisty2.ino]
2026-01-17 Update PicoMIDIcontroller_BOM.xlsx
    Corrected 4067 package, added links for most parts
    [PicoMIDIcontroller_BOM.xlsx]
2026-01-21 Added enclosure base design with provision for battery power
    Added an enclosure base with cutouts for a USB-C charger module and a switch. The the readme for more details.
    [Pico Midicontroller Base Battery Powered.stl]
